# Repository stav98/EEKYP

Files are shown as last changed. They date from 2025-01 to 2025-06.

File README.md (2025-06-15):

# EEKYP
Αποθετήριο με οδηγίες κατασκευής, πηγαίο κώδικα και σχέδια για το έργο <b>"Εξοικονόμηση Ενέργειας και Υδάτινων Πόρων στο δημόσιο σχολείο"</b><br>
**Ομάδα:** Ομάδα ρομποτικής Ε.Κ. Πρέβεζας - 1ου ΕΠΑ.Λ. Πρέβεζας<br/>
**Σχολείο:** Ε.Κ. Πρέβεζας - 1ο ΕΠΑ.Λ. Πρέβεζας (2024-25)<br/>
**Τίτλος έργου:** Εξοικονόμηση Ενέργειας και Υδάτινων Πόρων στο δημόσιο σχολείο<br/> 
<a href="https://openedtech.ellak.gr/robotics2025/exikonomisi-energias-ke-idatinon-poron-sto-dimosio-scholio-e-k-prevezas/">Η παρουσίαση του έργου στο site του ΕΕΛΛΑΚ</a><br>

<b>Τελευταία ενημέρωση 15-6-2025</b>

Περιγραφή έργου
========================
Η ομάδα μας στα πλαίσια του <a href="https://openedtech.ellak.gr/">7ου Πανελλήνιου Διαγωνισμού Ανοιχτών Τεχνολογιών στην Εκπαίδευση</a> ο οποίος διοργανώνεται από τον <a href="https://eellak.ellak.gr/">ΕΕΛΛΑΚ</a> και με θεματική ενότητα <b>"Ανοιχτή Σχεδίαση για έναν Άμεσο Δημόσιο Χώρο"</b> υλοποίησε ένα σύστημα εποπτείας και διαχείρισης ενέργειας και νερού για το σχολείο μας. Το σύστημα τοποθετήθηκε στους χώρους του εργαστηριακού κέντρου (Ε.Κ.) και λειτουργεί δοκιμαστικά. 

Συγκεκριμένα το σύστημα έχει δομηθεί στους τέσσερις ακόλουθους άξονες και στο σχήμα φαίνεται ο τρόπος λειτουργίας και η επικοινωνία των μονάδων:
<ul>
 <li>Α. Εξοικονόμηση νερού</li>
 <li>Β. Εξοικονόμηση ενέργειας</li>
 <li>Γ. Μετεωρολογικός σταθμός</li>
 <li>Δ. Κεντρικό σύστημα διαχείρισης</li>
</ul>

<p align = "center">
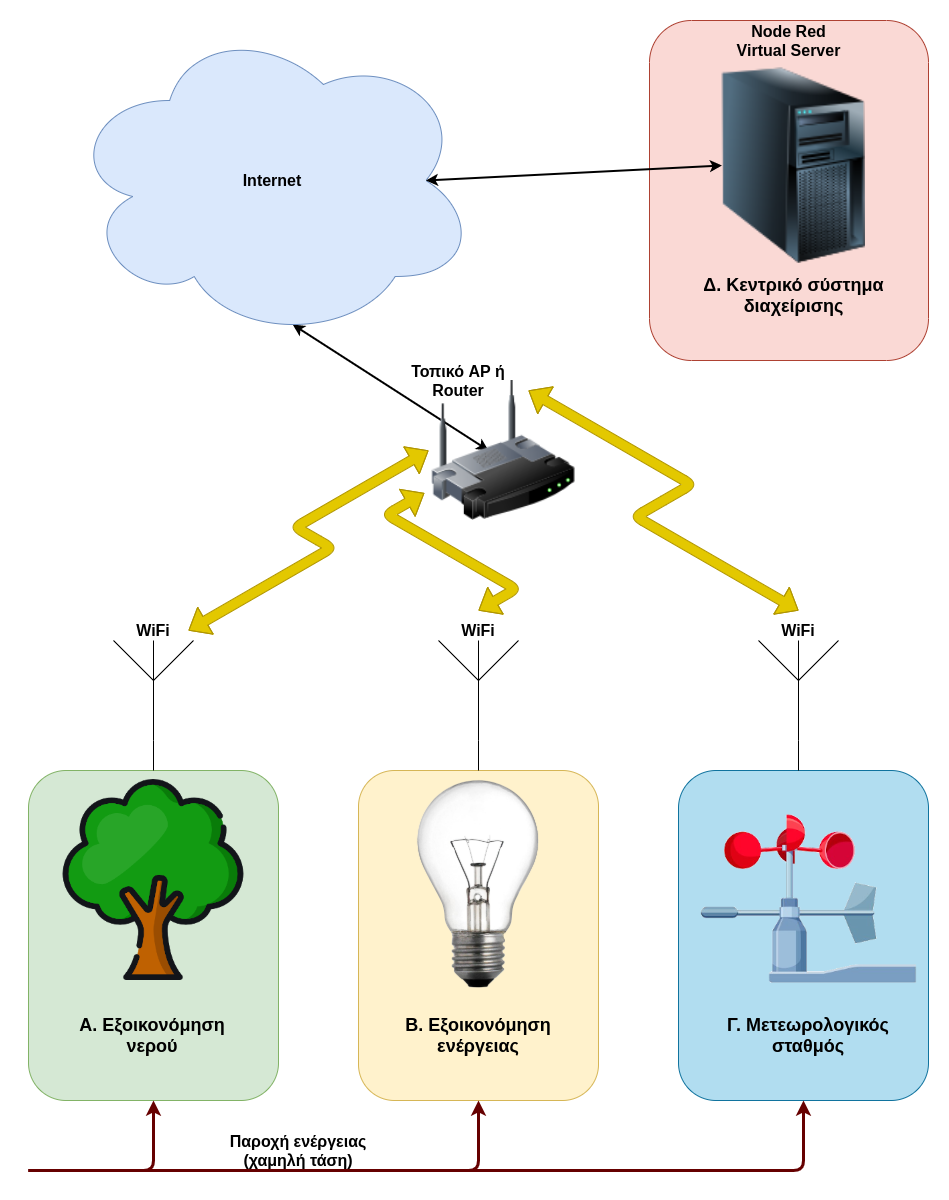
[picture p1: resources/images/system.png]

</p>

Περιεχόμενα
===========

<a href="/documentation/protasi.md">Αρχική πρόταση - Στόχοι - Λίστα υλικών - Προϋπολογισμός</a><br>
<a href="/documentation/eisagogi.md">Γενικές πληροφορίες</a><br>
<a href="Subsystem1_Irrigation/readme.md">Α. Εξοικονόμηση νερού</a><br>
<a href="Subsystem2_PowerSaving/readme.md">Β. Εξοικονόμηση ενέργειας</a><br>
<a href="Subsystem3_WeatherStation/readme.md">Γ. Μετεωρολογικός σταθμός</a><br>
<a href="Subsystem4_NodeRed/readme.md">Δ. Κεντρικό σύστημα διαχείρισης</a><br>

Συμμετέχοντες μαθητές
=====================
Οι μαθητές προέρχονται από το 1ο ΕΠΑ.Λ. Πρέβεζας και από τους τομείς Πληροφορικής - Ηλεκτρολογίας.
<ul>
 <li>Αργυρός Θεμιστοκλής</li>
 <li>Αδάμ Ευάγγελος</li>
 <li>Νάτση Παυλίνα</li>
 <li>Κόκκας Παναγιώτης</li>
</ul>

Υπεύθυνοι καθηγητές: Σταύρος Φώτογλου ΠΕ86 πληροφορικής, Κοτζαμουράτογλου Γιώργος ΠΕ83 ηλεκτρολογίας

Για την υλοποίηση του έργου χρησιμοποιήθηκε ο εξοπλισμός των εργαστηρίων του Εργαστηριακού Κέντρου (Ε.Κ.) Πρέβεζας. Τα υλικά που χρησιμοποιήθηκαν ήταν δωρεά του ΕΕΛΛΑΚ.

Λογισμικό που χρησιμοποιήθηκε
=====================
<p>Χρησιμοποιήθηκε αποκλειστικά λογισμικό ανοιχτού κώδικα.</p>
<ul>
 <li>Λειτουργικό σύστημα Linux. Στους σταθμούς εργασίας στους οποίους έγινε ο σχεδιασμός, ανάπτυξη του έργου υπήρχε εγκατεστημένο Ubuntu 24.04 Mate.</li>
 <li>Draw.io για σχεδιασμό διαγραμμάτων, κυκλωμάτων.</li>
 <li>FreeCad για σχεδιασμό των τρισδιάστατων μοντέλων.</li>
 <li>Gimp για επεξεργασία φωτογραφιών.</li>
 <li>Audacity για επεξεργασία ήχου.</li>
 <li>Simple Screen Recorder για σύλληψη video από την επιφάνεια εργασίας.</li>
 <li>OpenShot για επεξεργασία video.</li>
 <li>LibreOffice για τα κείμενα και εξαγωγή PDF.</li>
 <li>PlatfomIO μαζί με VsCode για την ανάπτυξη του λογισμικού.</li>
 <li>Ubuntu Linux 24.04 server στον εικόνικο διακομιστή με το Mosquitto MQTT brocker και το NodeRed. Επίσης στον φυσικό διακομιστή λειτουργεί Ubuntu 24.04 Server με KVM για εικονικά συστήματα και Docker για τα container.</li> 
</ul>

Βελτιώσεις που πρέπει να γίνουν άμεσα (TODO LIST)
========================================
Επειδή δεν προλάβαμε να ολοκληρώσουμε κατά 100% τον αρχικό σχεδιαμό, αλλά και νέες ιδέες που προέκυψαν κατά την υλοποίηση, την επόμενη σχολική χρονιά θα γίνουν οι ακόλουθες προσθήκες - βελτιώσεις:
<ol>
 <li>Υποσύστημα 1</li>
 <ul>
  <li>Προσθήκη κώδικα στο ESP01 και στο Arduino Nano ώστε να ρυθμίζεται η γωνία ανοίγματος της ηλεκτροβάνας</li>
  <li>Προσθήκη hardware και κώδικα ώστε να εμφανίζει και να στέλνει την τάση λειτουργίας. (Όπως γίνεται στο υποσύστημα 3)</li>
  <li>Υποστήριξη χωρητικών αισθητήρων για την υγρασία εδάφους.</li>
 </ul>
 <li>Υποσύστημα 2</li>
 <ul>
  <li>Προσθήκη hardware (1 σετ με relays) και κώδικα ώστε να συνδέεται με το κουδούνι του σχολείου. Θα προγραμματίζεται με web interface ή από το NodeRed και θα έχει ακρίβεια msec.</li>
  <li>Προσθήκη hardware και κώδικα ώστε να εμφανίζει και να στέλνει την τάση λειτουργίας. (Όπως γίνεται στο υποσύστημα 3)</li>
 </ul>
 <li>Υποσύστημα 3</li>
 <ul>
  <li>Βάψιμο με άσπρο σπρέυ των οργάνων για προστασία από τον ήλιο.</li>
  <li>Υπολογισμός της συσώρευσης βροχής.</li>
  <li>Καλύτερη βαθμονόμηση του ανεμόμετρου.</li>
  <li>Προσθήκη πινάκων διόρθωσης στο web interface του ESP01 ώστε εύκολα ο χρήστης να διορθώνει μη γραμμικές συμπεριφορές του ανεμόμετρου και μετρητή έντασης ηλιακής ακτινοβολίας.</li>
  <li>Προσθήκη hardware για καταμέτρηση των κοντινών κεραυνών (ακτίνα μέχρι 2Km).</li>
 </ul>
 <li>Υποσύστημα 4</li>
 <ul>
  <li>Στο αυτόματο πότισμα διόρθωση του εβδομαδιαίου προγραμματισμού όπως γίνεται για την διαχείρηση ενέργειας.</li>
  <li>Στην διαχείρηση ενέργειας να προστεθεί η γραμμή 2 όπως είναι η γραμμή 1.</li>
  <li>Στον μετεωρολογικό σταθμό να στέλνει δεδομένα κάθε 10 λεπτά στο Weather Cloud.</li>
  <li>Καλύτερη καταγραφή σε αρχεία της κατανάλωσης ρεύματος και νερού.</li>
  <li>Καλύτερη συνεργασία μεταξύ των τριών υποσυστημάτων.</li>
 </ul>
</ol>

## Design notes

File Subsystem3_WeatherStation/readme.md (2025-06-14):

<H3>Γ. Μετεωρολογικός σταθμός</H3>
Σχεδιάσαμε και κατασκευάσαμε έναν μετεωρολογικό σταθμό ο οποίος επικοινωνεί μέσω διαδικτύου με τον κεντρικό σύστημα διαχείρισης ώστε τα δεδομένα να χρησιμοποιούνται από τις προηγούμενες μονάδες. Επίσης στέλνει τα μετεωρολογικά δεδομένα στην ανοιχτή πλατφόρμα WeatherCloud. Τα περισσότερα όργανα του μετεωρολογικού σταθμού τα κατασκευάσαμε στον εκτυπωτή 3D του σχολείου.

Ο μετεωρολογικός σταθμός καταγράφει 8 μετεωρολογικά μεγέθη. Σε σχέση με τον αρχικό σχεδιασμό δεν βάλαμε τον αισθητήρα καταμέτρησης κεραυνών διότι δεν βρήκαμε τον αισθητήρα στην ελληνική αγορά. Ακολουθεί το block διάγραμμα της μονάδας και η τελική υλοποίηση σε λειτουργία:

<table align="center">
 <tr>
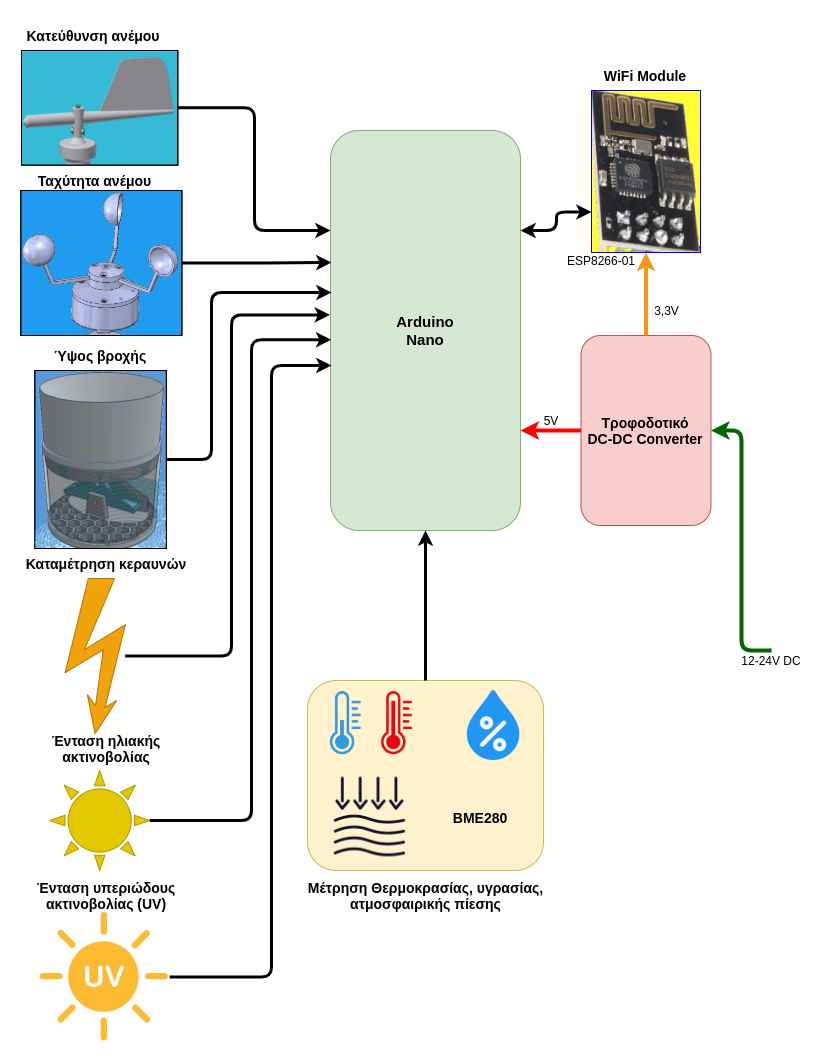
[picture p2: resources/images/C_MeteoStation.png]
  <td></td>
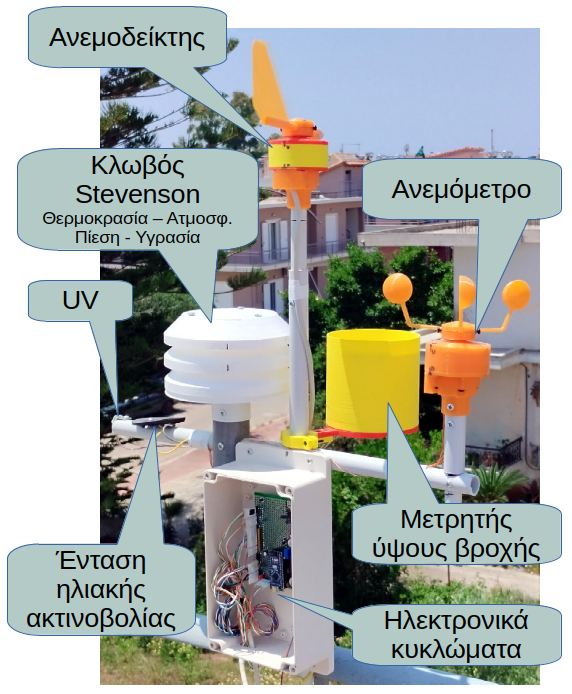
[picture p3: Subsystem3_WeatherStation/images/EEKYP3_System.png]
  <td></td>
  </tr>
</table>

<H3>Κατασκευή ηλεκτρονικού κυκλώματος</H3>
Έγινε κατασκευή του πρωτοτύπου σε διάτρητη πλακέτα perfboard. Πάνω στην πλακέτα τοποθετήθηκαν όλα τα εξαρτήματα και τα αρθρώματα και κολλήθηκαν από την κάτω πλευρά με λεπτά σύρματα. Ακολουθεί το θεωρητικό κύκλωμα της μονάδας.
<p align = "center">
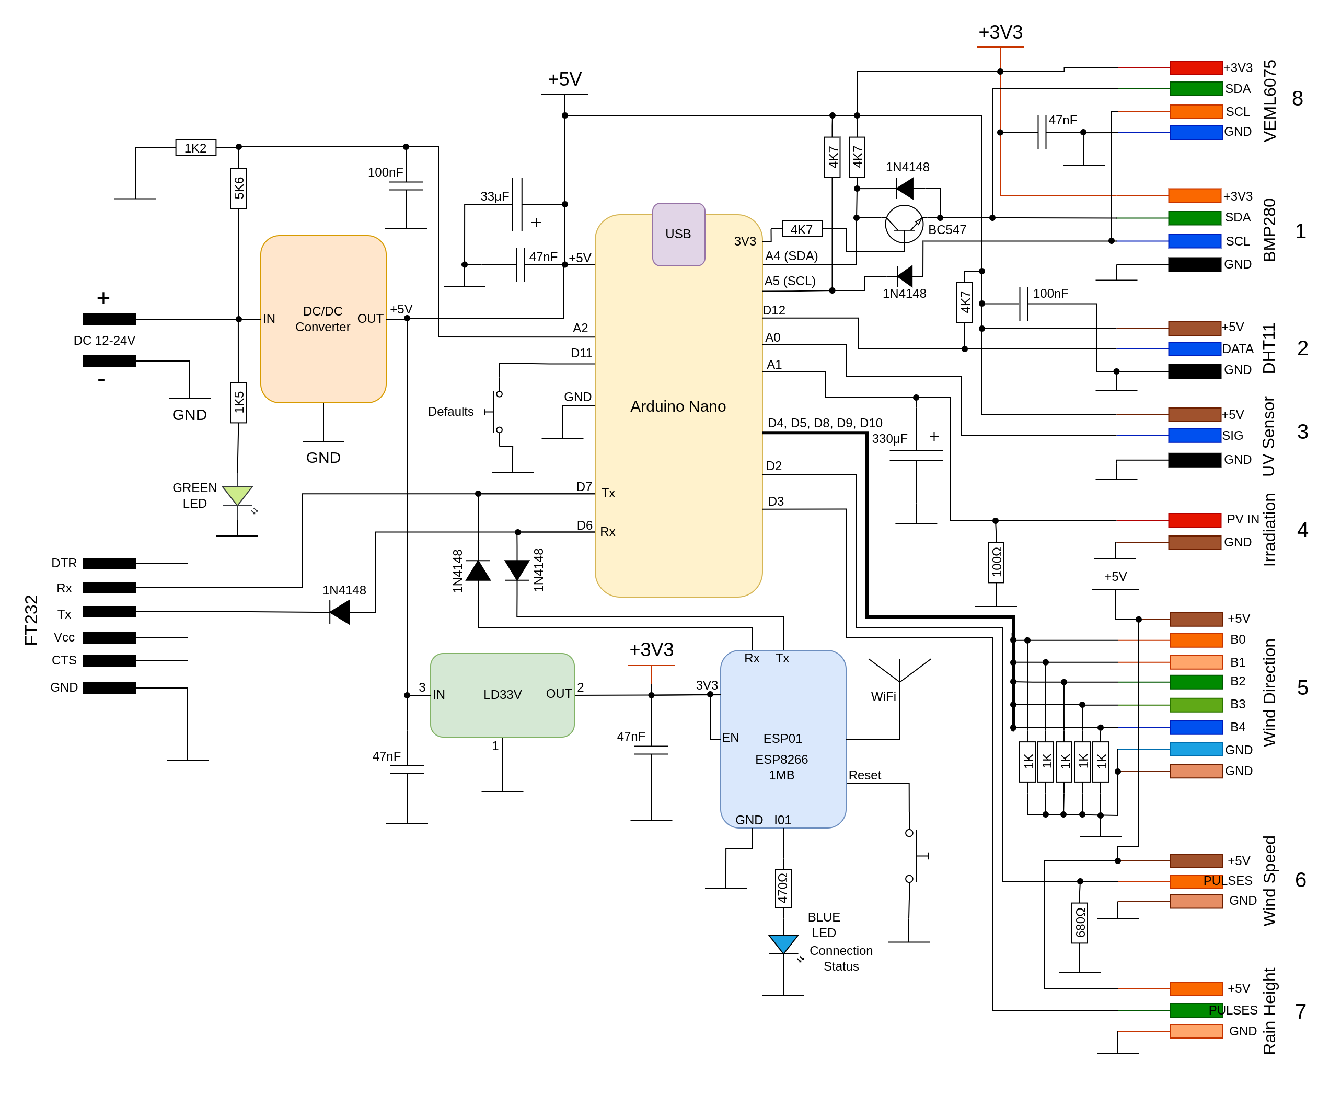
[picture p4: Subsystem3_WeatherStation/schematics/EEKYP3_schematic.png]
  
</p>

<p>
 Στις ακόλουθες εικόνες φαίνεται η κατασκευή του πρωτοτύπου σε πλακέτα perfboard.
</p>
<table align="center">
 <tr>
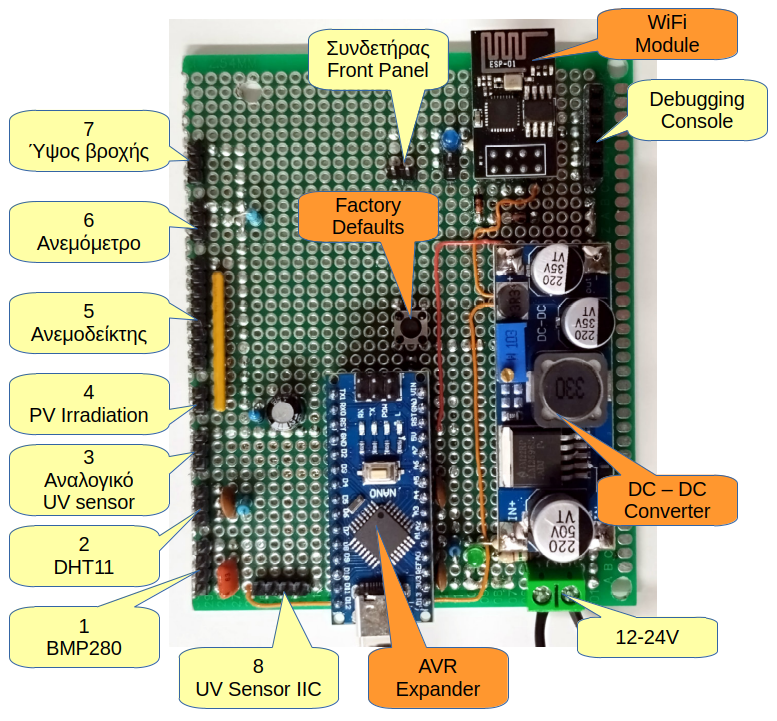
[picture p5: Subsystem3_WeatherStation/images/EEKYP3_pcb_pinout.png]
  <td></td>
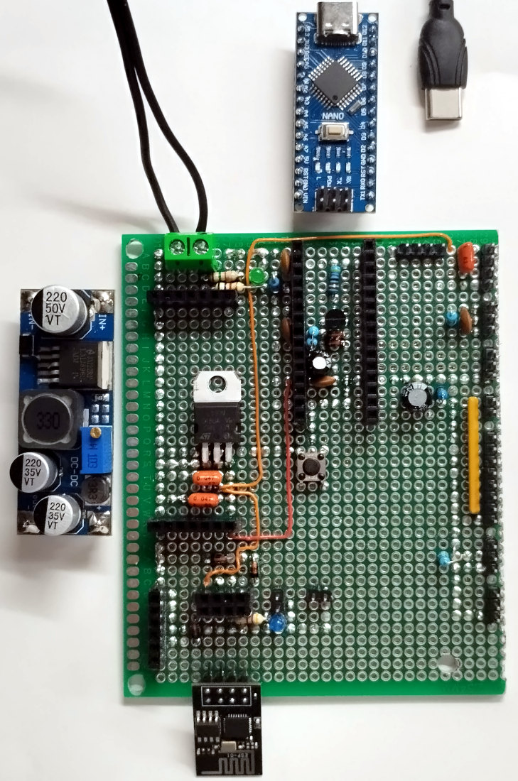
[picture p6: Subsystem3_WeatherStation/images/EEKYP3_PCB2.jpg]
  <td></td>
  </tr>
</table>

Ακολουθεί η περιγραφή όλων των οργανών και παρουσιάζεται ο τρόπος κατασκευής τα σχέδια και ο τρόπος βαθμονόμησης:

## Ανεμόμετρο

Το ανεμόμετρο μετράει την ταχύτητα του ανέμου. Την ιδέα την βρήκαμε στο https://www.yoctopuce.com/EN/article/how-to-measure-wind-part-1 και τα αρχεία για την εκτύπωση 3D υπάρχουν στον κατάλογο 3D.

### Τροποποιήσεις

1. Ρουλεμάν. Τα δύο ρουλεμάν έχουν διαστάσεις 9mm(εξωτερ.), 5mm(εσωτερ.), 3mm(ύψος) και προέρχονται από κεφαλές παλαιών HDD 3,5".
2. Άξονας. Για άξονα χρησιμοποιήσαμε βίδα 5mm(4,9) και την κόψαμε σε μήκος 51mm. Στο κάτω άκρο χαράξαμε εγκοπή ώστε να μπαίνει πλακέ κατσαβίδι.
3. Επειδή υπάρχουν μικρά κενά στην εφαρμογή των ρουλεμάν με την φωλιά, κόβουμε κομμάτι αυτοκόλλητης αλουμινοταινίας 4,5mm x 100mm και τυλίγουμε 2-3 στροφές στην εξωτερική πλευρά των ρουλεμάν.
4. Το ίδιο γίνεται και στον άξονα στα δύο σημεία που εφάπτεται με τα ρουλεμάν. Ταινία αλουμινίου 6,5mm x 56mm και τυλίγουμε 2 στροφές στον άξονα.
5. Μεγαλώνουμε τις οπές στα καπάκια πάνω και κάτω σε διάμετρο 6,6 - 7mm ώστε να περνάει άνετα ο άξονας.
6. Στον εσωτερικό δίσκο με τις 4 σχισμές μεγαλώνουμε την κεντρική οπή σε 4mm και με σπειροτόμο 5mm κάνουμε στροφές. Για σταθεροποίηση, από την πάνω πλευρά βάζουμε ροδέλα στην οποία έχουμε κάνει στροφές και βιδώνει κόντρα.
7. Στον ρότορα με τα κουτάλια μεγαλώνουμε την οπή σε 4mm και κάνουμε στροφές.
8. Ο εσωτερικός δίσκος βιδώνεται στον άξονα. Το ίδιο γίνεται και στον ρότορα κρατώντας με κατσαβίδι πλακέ τον άξονα από κάτω.
9. Για φωτοδίοδο και φωτοτρανζίστορ χρησιμοποιούμε το υπέρυθρο TCRT5000. Βγάζουμε τα δύο στοιχεία από το πλαστικό πλαίσιο και βάζουμε το φωτοτρανζίστορ από την πάνω πλευρά και την φωτοδίοδο από την κάτω.
10. Η φωτοδίοδος συνδέεται στα +5V μέσω αντιστάτη 220Ω και ο συλλέκτης του τρανζίστορ πάει στα +5V. Στην πλακέτα ο εκπομπός γειώνεται μέσω αντιστάτη pulldown 1Κ.

Για την σύνδεση με την πλακέτα θέλουμε 3 καλώδια (5V, GND και τα δεδομένα από τον εκπομπό του φωτοτρανζίστορ που είναι παλμοί μεταβλητής συχνότητας ανάλογα με την ταχύτητα περιστροφής του ρότορα.)

<table align="center">
 <tr>
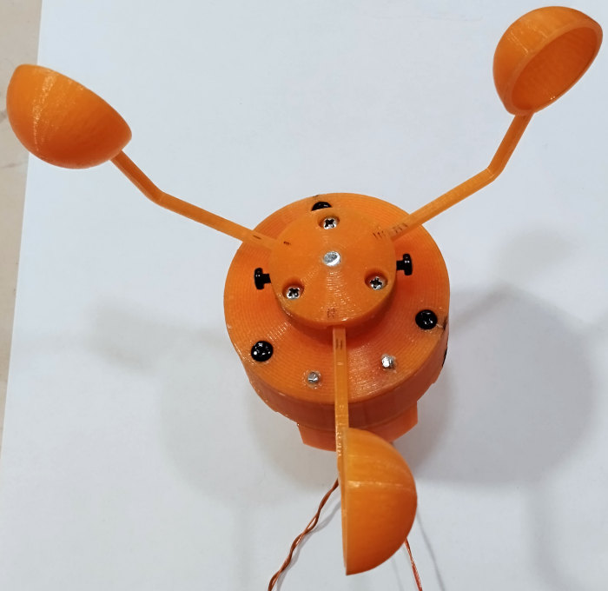
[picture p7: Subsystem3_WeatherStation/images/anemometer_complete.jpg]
  <td></td>
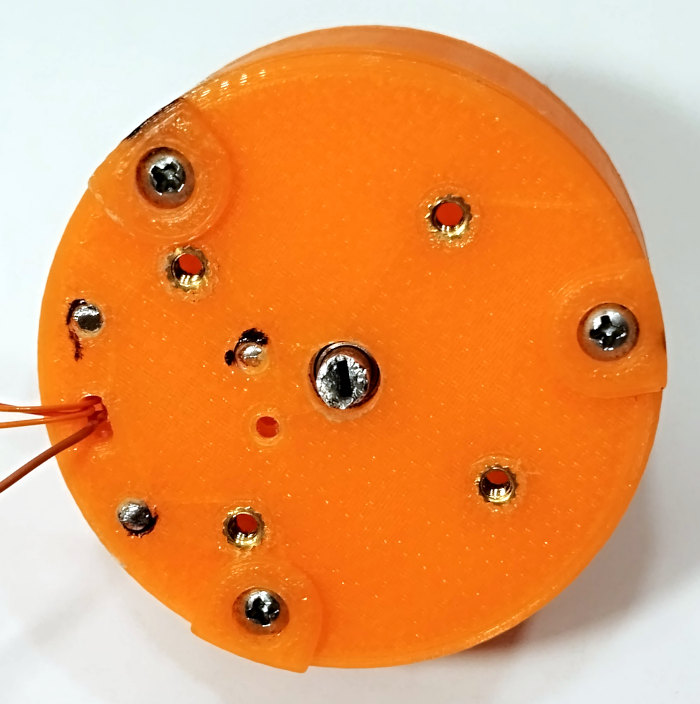
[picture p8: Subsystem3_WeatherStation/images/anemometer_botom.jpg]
  <td></td>
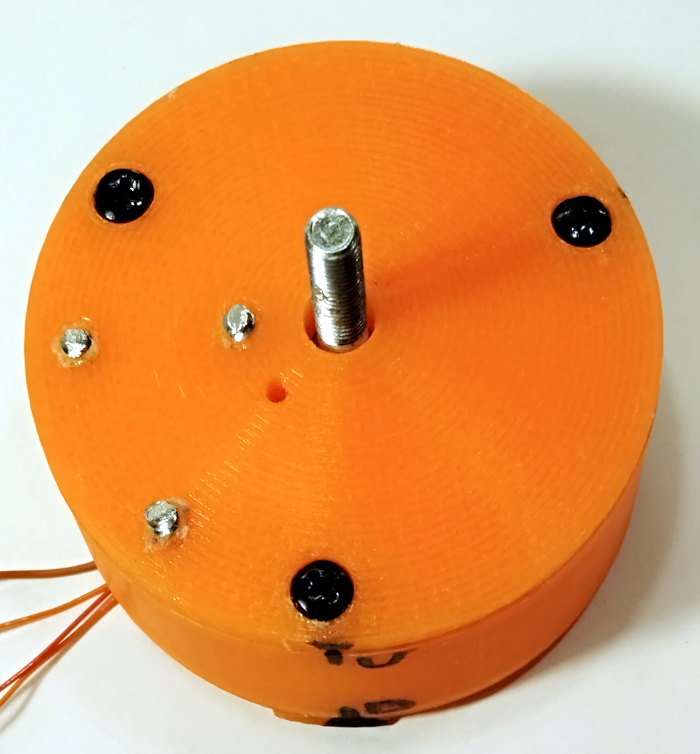
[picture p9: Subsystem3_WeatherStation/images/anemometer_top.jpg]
   <td></td>
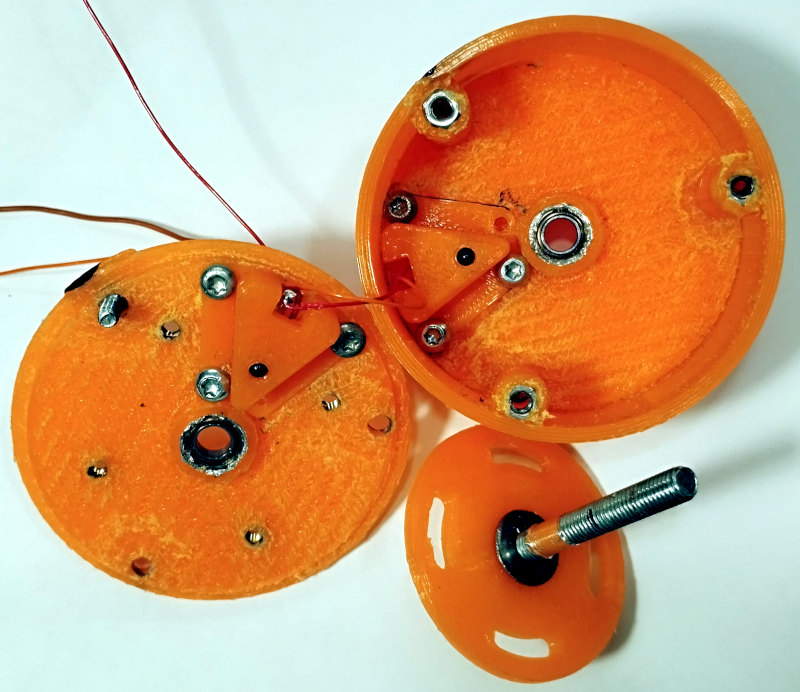
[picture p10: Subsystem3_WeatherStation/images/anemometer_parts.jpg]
   <td></td>
  </tr>
</table>

<p align = "center">
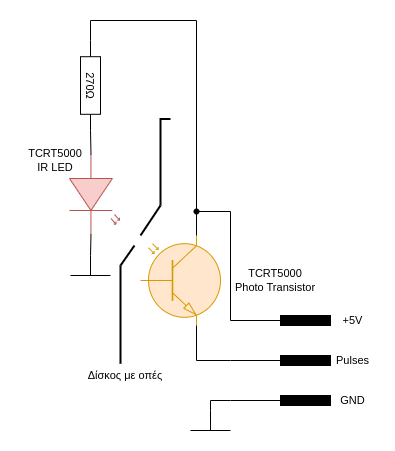
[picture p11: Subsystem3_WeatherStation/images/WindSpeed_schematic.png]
  
</p>

### Βαθμονόμηση

Μια μέρα με άπνοια τοποθετούμε το ανεμόμετρο σταθερά σε ένα αυτοκίνητο. Προσοχή !!! πρέπει να δεθεί πολύ σταθερά ώστε να αποφύγουμε ατυχήματα. Επίσης πρέπει να είναι αρκετά πάνω από την οροφή. Με ένα φορητό υπολογιστή συνδεδεμένο στο Arduino nano και παρουσιάζοντας τις μετρήσεις στο πρόγραμμα τερματικού PUTTY μετράμε τις στροφές / λεπτό της περιστροφής του ρότορα. (Για μια στροφή έχουμε 4 διακοπές). Καταγράφουμε τα rpm για ταχύτητες από 10 - 80Km/h με βήμα ανά 10Km/h. Αν υπάρχει μη γραμμική σχέση βάζουμε αυτές τις τιμές σε πίνακα και υπολογίζουμε τις ενδιάμεσες τιμές.  

## Ανεμοδείκτης

Ο ανεμοδείκτης δείχνει την κατεύθυνση του ανέμου. Την ιδέα την βρήκαμε στο https://www.yoctopuce.com/EN/article/how-to-measure-wind-part-2 και τα αρχεία για την εκτύπωση 3D υπάρχουν στον κατάλογο 3D. Ο ανεμοδείκτης μας χρησιμοποιεί την τεχνική του κώδικα Gray και συγκεκριμένα το Single Track Gray Code (STGC). Εδώ έχουμε 5 υπέρυθρα Led στο κάτω μέρος του οργάνου τα οποίο επισκιάζονται ή όχι ανάλογα με την θέση του δίσκου. Οι τρεις οπές του δίσκου έχουν μήκη σύμφωνα με τον κώδικα Gray 5 bit. Από την πάνω πλευρά υπάρχουν 5 υπέρυθρα φωτοτρανζίστορ ακριβώς απέναντι από καθένα Led. Οι δυνατοί συνδιασμοί που παράγονται με 5 bits είναι 32, αλλά σύμφωνα με τον τροποποιημένο κώδικα μπορούμε να έχουμε 30 συνδιασμούς. Δηλαδή 360 μοίρες / 30 = 12 μοίρες. Επομένως μπορούμε να ανιχνεύσουμε 30 διαφορετικές διευθύνσεις του ανέμου το οποίο είναι υπέρ αρκετό. Για τα υπέρυθρα Led και φωτοτρανζίστορ χρησιμοποιήθηκαν 5 TCRT5000. <a href="docs/Gray_code.pdf" title="Παρουσίαση κώδικα">Εδώ στο αρχείο</a> υπάρχουν οι συνδιασμοί του τροποποιημένου κώδικα που χρησιμοποιήσαμε.

<p align = "center">
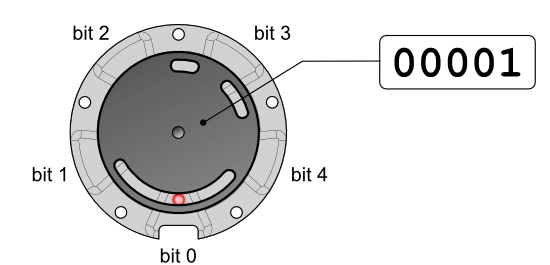
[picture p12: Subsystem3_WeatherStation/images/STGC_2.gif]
  
</p>

### Τροποποιήσεις

Οι τροποποιήσεις είναι ίδιες με αυτές του ανεμόμετρου.

Για την σύνδεση με την πλακέτα θέλουμε 7 καλώδια (5V, GND και τα δεδομένα των 5 bits του κώδικα Gray.)

<table align="center">
 <tr>
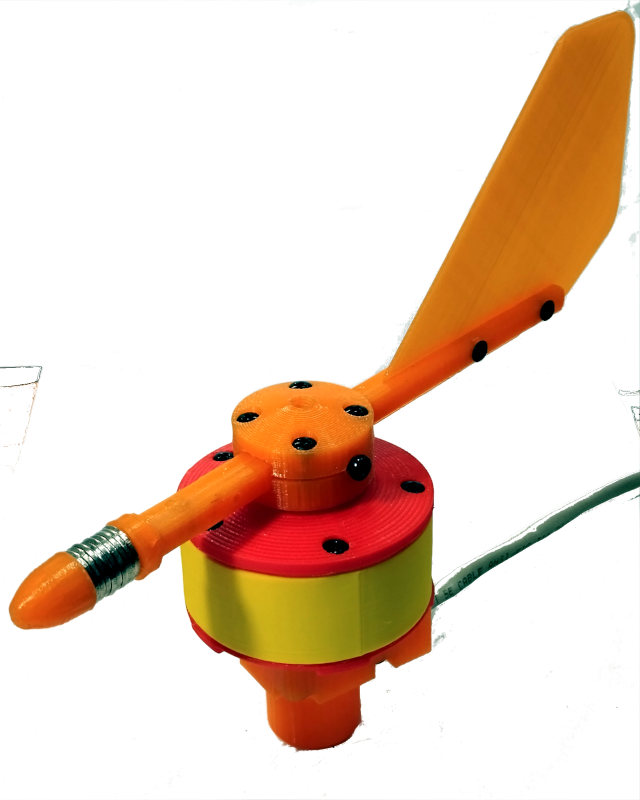
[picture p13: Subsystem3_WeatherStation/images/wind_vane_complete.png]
  <td></td>
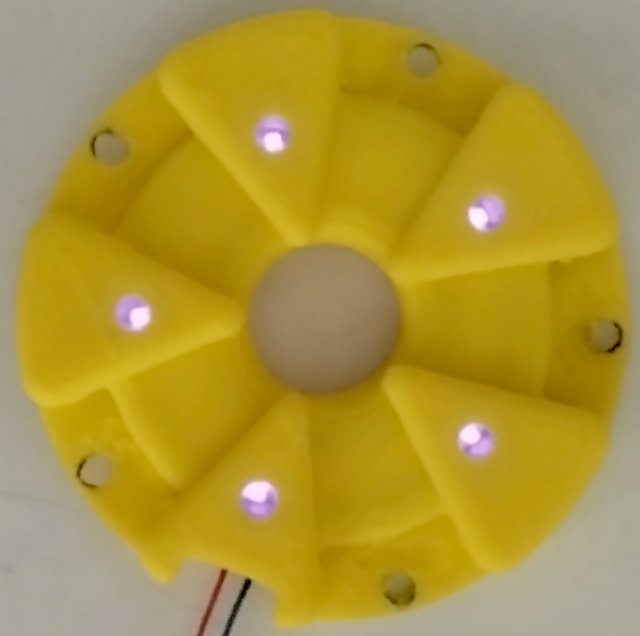
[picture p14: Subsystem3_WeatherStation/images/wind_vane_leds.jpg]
  <td></td>
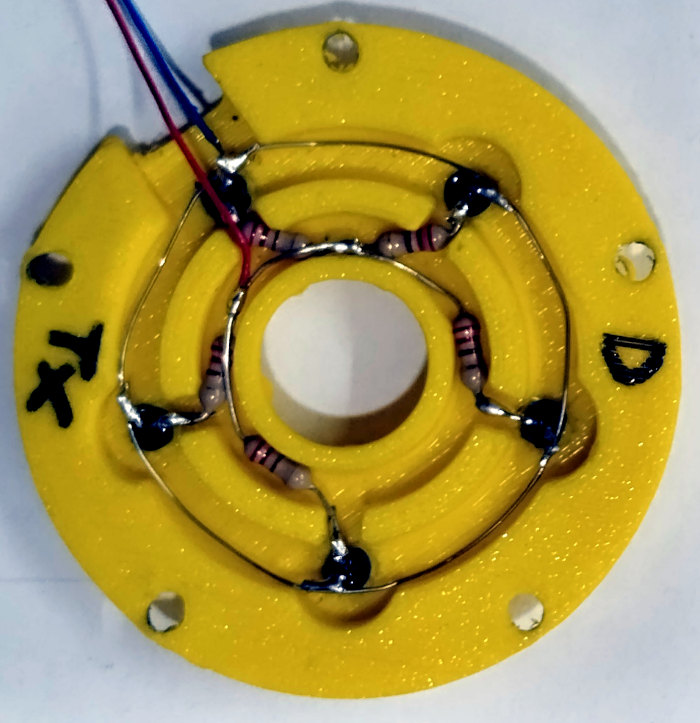
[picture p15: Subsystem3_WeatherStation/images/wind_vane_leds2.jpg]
   <td></td>
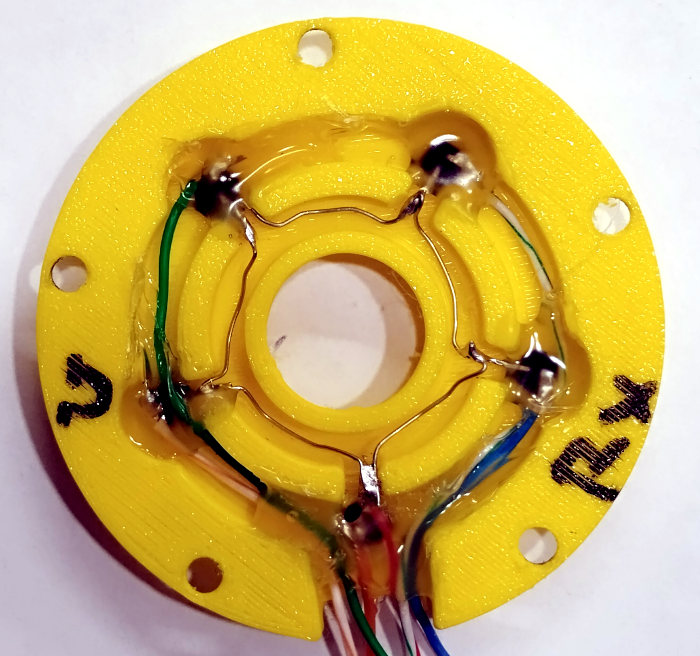
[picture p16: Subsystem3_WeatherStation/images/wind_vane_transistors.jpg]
   <td></td>
  </tr>
</table>

<table align="center">
 <tr>
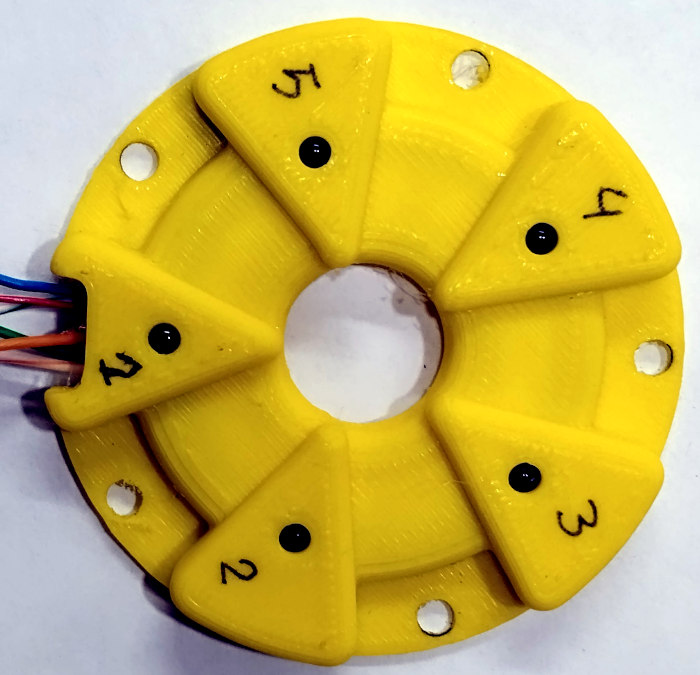
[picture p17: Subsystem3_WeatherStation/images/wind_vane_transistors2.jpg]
  <td></td>
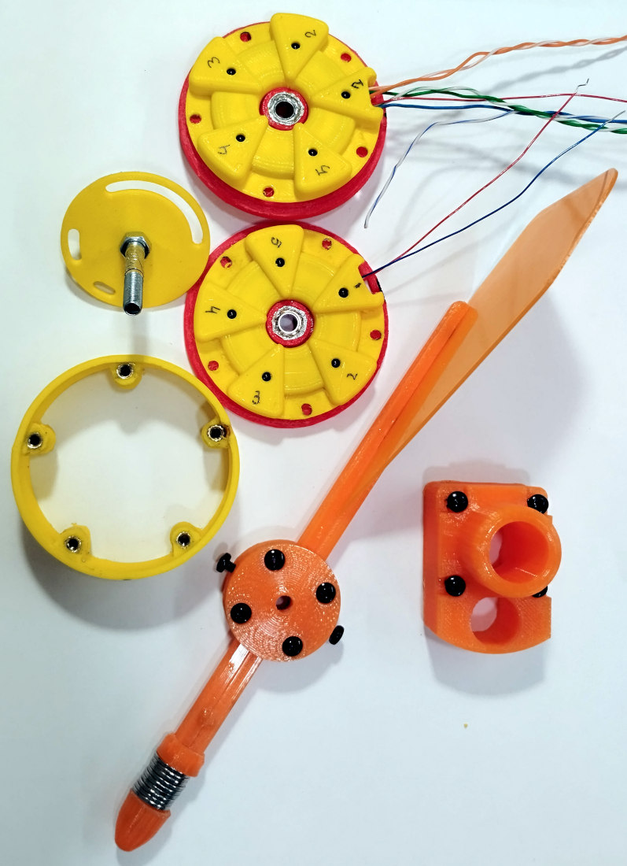
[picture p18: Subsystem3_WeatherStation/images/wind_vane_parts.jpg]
  <td></td>
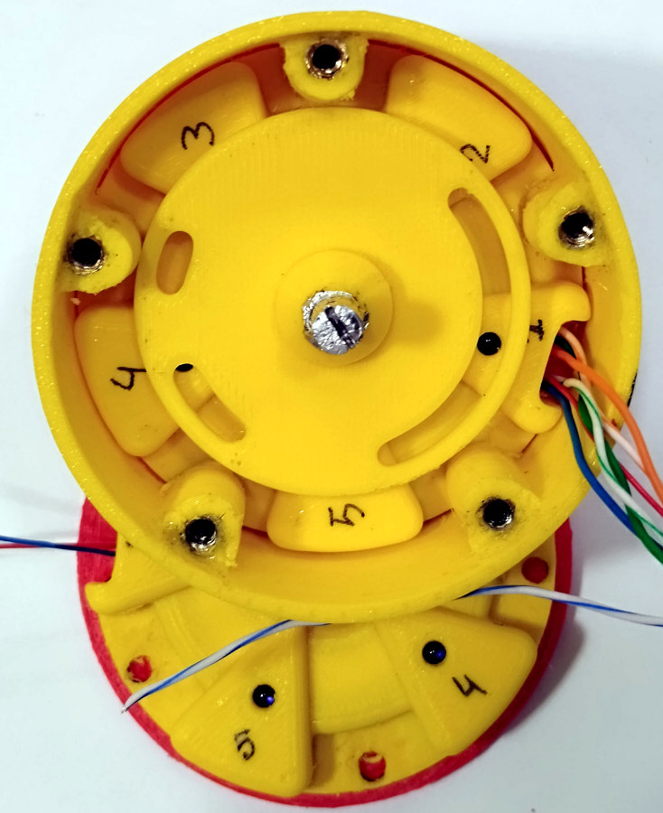
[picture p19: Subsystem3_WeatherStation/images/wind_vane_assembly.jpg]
   <td></td>
  </tr>
</table>

<p align = "center">
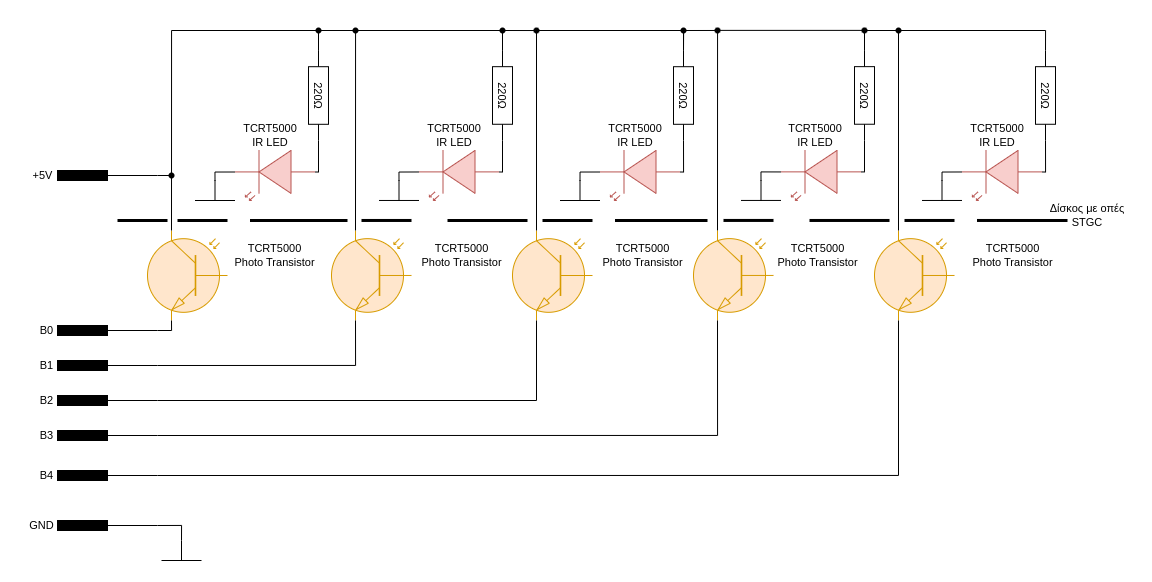
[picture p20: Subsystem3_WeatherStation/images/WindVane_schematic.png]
  
</p>

### Βαθμονόμηση
Η βαθμονόμηση του ανεμοδείκτη είναι εύκολη. Φροντίζουμε να περιστρέψουμε όλο το σώμα του ανεμοδείκτη έτσι ώστε όταν ο ανεμοδείκτης είναι στραμμένος στις 0 μοίρες να δείχνει στον βορά.

## Μετρητής ύψους βροχής

Ο μετρητής ύψους βροχής μετράει την βροχόπτωση σε χιλιοστά. Τα αρχεία για την εκτύπωση 3D υπάρχουν στον κατάλογο 3D. Το νερό συλλέγεται από ένα χωνί διαμέτρου 9,6cm και οδηγείται σε ένα μηχανισμό τραμπάλας με δύο μικρά δοχεία στα άκρα. Όταν το δοχείο γεμίσει, η τραμπάλα γυρίζει λόγω της βαρύτητας και αδειάζει το νερό, ενώ το άλλο άκρο έχει ανέβει και γεμίζει από το χωνί. Όσο πιο πολύ είναι το νερό τόσο γρηγορότερα πάλλεται η τραμπάλα. Στα δύο άκρα έχουν τοποθετηθεί δύο μικροί μαγνήτες ίδιου βάρους. Εμείς ανιχνεύουμε τις ταλαντώσεις του ενός άκρου με έναν αισθητήρα hall. Το παλμικό σήμα οδηγείται σε ένα pin του arduino με δυνατότητα διακοπής. (External interrupt)  

<p align = "center">
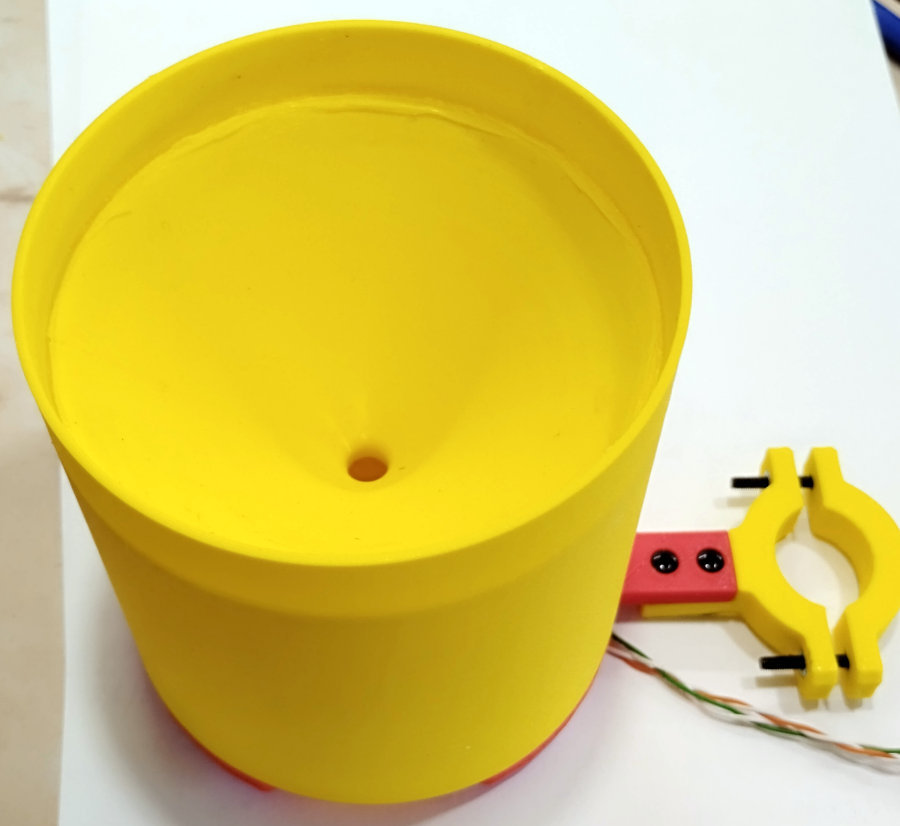
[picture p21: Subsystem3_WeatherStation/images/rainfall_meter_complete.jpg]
  
</p>

### Τροποποιήσεις

Για άξονα χρησιμοποιήσαμε μια βίδα διαμέτρου 3mm και για μαγνήτες βάλαμε μικρά κομματάκια από μαγνήτη κίνησης της κεφαλής ενός σκληρού δίσκου. Σπάμε τον μαγνήτη σε μικρά κομμάτια ίδιου μεγέθους. Από τους δύο μαγνήτες μόνο ο ένας χρησιμοποιείται ενώ ο άλλος λειτουργεί ως αντίβαρο. Επίσης πρέπει να προσέξουμε στην τοποθέτηση των πόλων του ενεργού μαγνήτη ώστε το μαγνητικό πεδίο να επιδρά στον αισθητήρα hall. 

Για την σύνδεση με την πλακέτα θέλουμε 3 καλώδια (5V, GND και το παλμικό σήμα)

<table align="center">
 <tr>
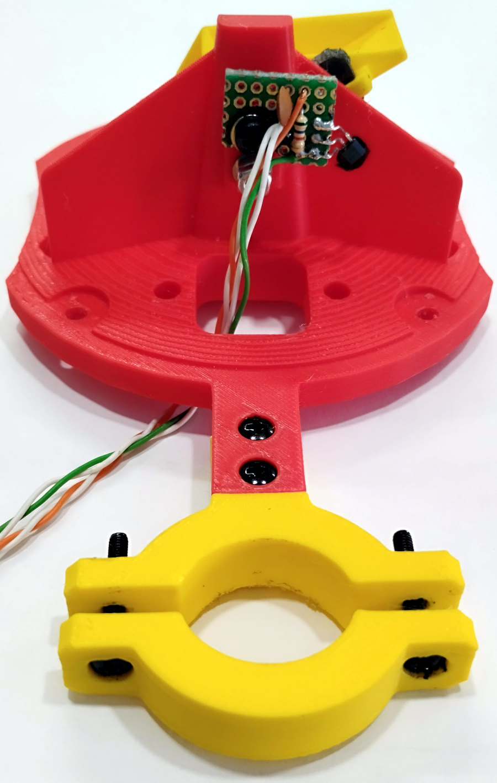
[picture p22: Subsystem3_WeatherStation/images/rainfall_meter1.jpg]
  <td></td>
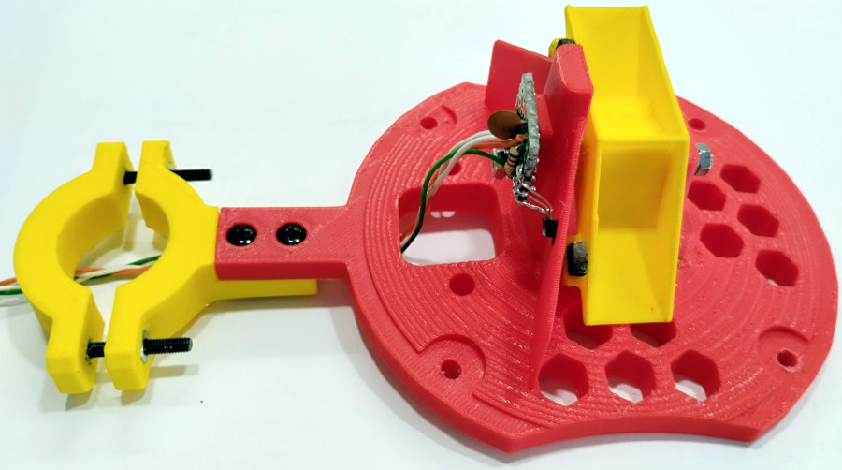
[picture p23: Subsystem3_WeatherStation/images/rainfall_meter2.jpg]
  <td></td>
  </tr>
</table>

<p align = "center">
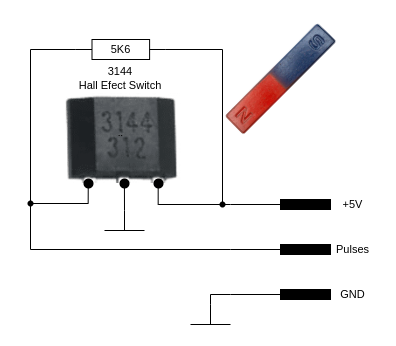
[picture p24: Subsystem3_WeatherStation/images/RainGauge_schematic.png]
  
</p>

### Βαθμονόμηση

Με μια σύριγγα στάζουμε νερό στην τραμπάλα και βρίσκουμε τα ml που χρειάζονται για να αλλάξει η κατάσταση. Είδαμε ότι με 3 ml αλλάζει η ισορροπία της τραμπάλας. Για μεγαλύτερη ακρίβεια χρησιμοποιούμε μια σύριγγα 20ml και στάζουμε αργά νερό στο χωνί και μετράμε παλμούς. Έτσι μετρήσαμε ότι για 20ml κάνει 7 παλμούς και για 40ml κάνει 14 παλμούς. Δηλαδή 20 / 7 = 2,9ml ανά παλμό. Επειδή κάνουμε διακοπή στον microcontroller με κάθοδο παλμού τότε για 3ml θα μετρήσει ένα παλμό. Και τώρα λίγοι υπολογισμοί:

Διάμετρος χωνιού 9,6cm δηλαδή ακτίνα 4,8cm δηλαδή εμβαδόν = π*r<sup>2</sup> = 3.14 * 4,8<sup>2</sup> = 72,4cm<sup>2</sup>.
Επομένως αν το ύψος νερού είναι 10mm = 1cm τότε ο όγκος θα είναι 72,4cm<sup>2</sup> * 1cm = 72,4cm<sup>3</sup> ή 72,4ml.
72,4ml / 3ml = 24 παλμοί. Και σύμφωνα με τα παραπάνω δημιουργείται ο ακόλουθος πίνακας.

<table align="center">
 <tr>
  <td><strong>Ύψος</strong></td><td><strong>Όγκος</strong></td><td><strng>Παλμοί</strng></td>
 </tr>
 <tr>
  <td>10mm</td><td>72,4ml</td><td>24</td>
 </tr>
 <tr>
  <td>20mm</td><td>144,8ml</td><td>46</td>
 </tr>
 <tr>
  <td>30mm</td><td>217,2ml</td><td>72</td>
 </tr>
 <tr>
  <td>40mm</td><td>290ml</td><td>96</td>
 </tr> 
 <tr>
  <td>50mm</td><td>362,4ml</td><td>120</td>
 </tr>
</table>

Αν σε μια ώρα μετρήσουμε π.χ. 10 παλμούς τότε έχουμε 10 * 3 = 30ml / 7,24 = 4,1mm ύψος βροχής. Για κάθε 1mm ύψος βροχής ο μικροελεγκτής δέχεται 2,5 παλμούς. 
Ή για κάθε 1mm βροχής έχουμε όγκο 7,24ml => 7,24 / 2,9 = 2,5 παλμοί.

## Αισθητήρες ατμοσφαιρικής πίεσης, θερμοκρασίας και υγρασίας
Οι αισθητήρες αυτοί τοποθετούνται σε μια μικρή πλακέτα η οποία με την σειρά της τοποθετείται μέσα στον μετεωρολογικό κλωβό τύπου Stevenson που εκτυπώσαμε στον εκτυπωτή 3D. Για την θερμοκρασία και την ατμοσφαιρική πίεση χρησιμοποιήσαμε τον αισθητήρα BMP280 ο οποίος συνδέεται με το Arduino nano με διασύνδεση IIC. Για μέτρηση της σχετικής υγρασίας χρησιμοποιήσαμε τον αισθητήρα DHT11 ο οποίος παρέχει επιπλέον και μέτρηση θερμοκρασίας. Ο DHT11 συνδέεται με ένα ξεχωριστό σειριακό δίαυλο.

<table align="center">
 <tr>
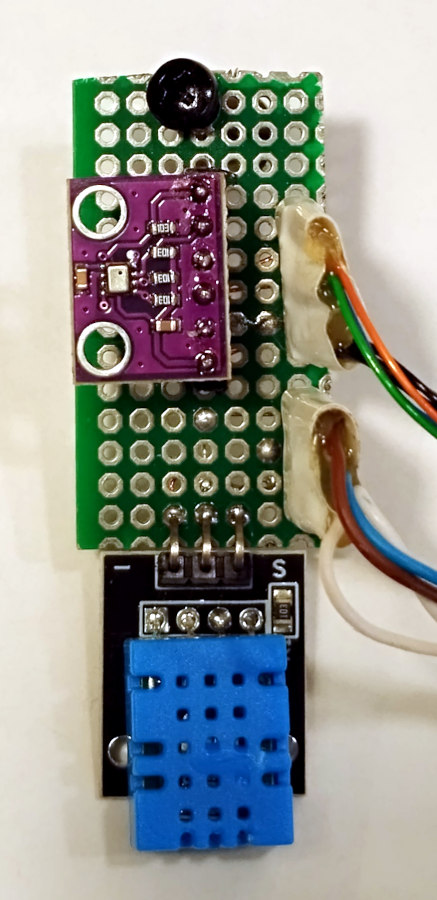
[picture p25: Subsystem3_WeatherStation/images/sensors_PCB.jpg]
  <td></td>
  <td></td>
  </tr>
</table>

## Αισθητήρες ακτινοβολίας UV και έντασης ηλιακής ακτινοβολίας
<p>Για την μέτρηση του δείκτη υπέρυθρης ακτινοβολίας UV έχουμε την δυνατότητα να χρησιμοποιήσουμε δύο αισθητήρες. Τον αναλογικό SEN0162 ο οποίος συνδέεται σε μια αναλογική είσοδο του arduino nano ή τον ψηφιακό VEML6075 ο οποίος συνδέεται με δίαυλο IIC και είναι πολύ πιο ακριβής και ευαίσθητος από τον πρώτο. Εμείς στην τελική φάση προτιμήσαμε τον ψηφιακό.</p>

<p>Για την μέτρηση της έντασης ηλιακής ακτινοβολίας πρέπει να χρησιμοποιηθεί ένα ειδικό όργανο που ονομάζεται πυρανόμετρο. Επειδή έχει υψηλό κόστος προτιμήσαμε να βάλουμε ένα μικρό φωτοβολταϊκό 3x3cm το οποίο συνδέεται σε μια αναλογική είσοδο. Με την μέθοδο αυτή δεν έχουμε καλή ακρίβεια αλλά αρκετή για ένα μαθητικό έργο. Και τα δύο όργανα και ειδικά ο μετρητής ακτινοβολίας UV πρέπει να τοποθετηθούν έξω από κάθε κουτί ή τζάμι γιατί έχουμε μεγάλη απόσβεση της ακτινοβολίας UV. Για να προστατέψουμε τον αισθητήρα από την υγρασία τον περνάμε πολλές στρώσεις διάφανο πλαστικοποιητικό σπρέυ εκτός από το παραθυράκι για την είσοδο του φωτός.</p>

<table align="center">
 <tr>
  <td></td>
  <td></td>
  </tr>
</table>

## Λογισμικό
<p>Το λογισμικό όπως και στα άλλα υποσυστήματα είναι γραμμένο σε γλώσσα wiring (c - c++) και για τους δύο microcontrollers. Επιπλέον υπάρχει και αρκετή HTML, CSS και JavaScript (JQuery) για την υλοποίηση του web interface.</p>

<table align="center">
 <tr>
  <td></td>
  <td></td>
  </tr>
</table>

Βίντεο δοκιμών του μετεωρολογικού σταθμού
<p align = "center"></p>

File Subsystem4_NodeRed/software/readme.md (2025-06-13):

Εδώ βρίσκονται τα flows για το Node Red.

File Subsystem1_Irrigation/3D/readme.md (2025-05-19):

Αρχεία για εκτύπωση στον εκτυπωτή 3D των βάσεων στήρηξης των βανών και των servomotors.

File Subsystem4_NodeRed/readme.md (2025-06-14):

<H3>Δ. Κεντρικό σύστημα διαχείρισης</H3>
Αυτό είναι το σύστημα συλλογής και καταγραφής δεδομένων από τις προηγούμενες μονάδες. Έχει υλοποιηθεί με το λογισμικό ανοιχτού κώδικα Node RED το οποίο λειτουργεί σε έναν εικονικό διακομιστή (KVM) του Ε.Κ Πρέβεζας. Εδώ υπάρχουν τρεις καρτέλες (tabs) μία για κάθε υποσύστημα. Σε αυτό το υποσύστημα γίνεται η επεξεργασία των ακατέργαστων δεδομένων από τα τρία προηγούμενα. Έτσι μπορούν να ληφθούν αποφάσεις π.χ. πότε πρέπει να ξεκινήσει το πότισμα, πόσο νερό καταναλώθηκε τον προηγούμενο μήνα ή πότε πρέπει να ανάψουν τα φώτα κλπ. Επίσης τα δεδομένα καταγράφονται και παρουσιάζονται με γραφήματα. Τέλος υπάρχει η δυνατότητα αποστολής μηνυμάτων μέσω Viber ή Telegram ακόμη και ο χειρισμός των δύο πρώτων υποσυστημάτων.</p>

Στην εικόνα φαίνεται η διεπαφή χρήστη του Node Red 
<p align = "center">
  
</p>

Και ο τρόπος προγραμματισμού με blocks και NodeJS (Java Script)
<p align = "center">
  
</p>

Βίντεο παρουσίασης των λειτουργιών του υποσυστήματος 3
<p align = "center"></p>

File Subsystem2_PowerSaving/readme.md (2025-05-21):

<H3>Β. Εξοικονόμηση ενέργειας</H3>
Κατασκευάσαμε μονάδα εποπτείας και ελέγχου σε δύο γραμμές φωτισμού για τον διάδρομο του Ε.Κ. Η μονάδα μετράει συνεχώς την κατανάλωση ενέργειας της παροχής και ανάβει μόνο τα απαραίτητα φώτα ανάλογα με το φως ημέρας. Η μονάδα επικοινωνεί μέσω διαδικτύου με το κεντρικό σύστημα διαχείρισης.
<p align = "center">
  
</p>
<H3>Κατασκευή ηλεκτρονικού κυκλώματος</H3>
Έγινε κατασκευή του πρωτοτύπου σε διάτρητη πλακέτα perfboard. Πάνω στην πλακέτα τοποθετήθηκαν όλα τα εξαρτήματα και τα αρθρώματα και κολλήθηκαν από την κάτω πλευρά με λεπτά σύρματα. Ακολουθεί το θεωρητικό κύκλωμα της μονάδας.
<p align = "center">
  
</p>
Η τελική μορφή του πρωτοτύπου και η τοποθέτηση του στο αδιάβροχο ηλεκτρολογικό κουτί.
<table align="center">
 <tr>
  <td></td>
  <td></td>
   <td></td>
  </tr>
</table>
Στην ακόλουθη εικόνα φαίνεται η περιγραφή των αρθρωμάτων και των συνδέσεων.
<p align = "center">
  
</p>

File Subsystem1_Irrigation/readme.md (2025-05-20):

<H2>Α. Εξοικονόμηση νερού</H2>
Σχεδιάσαμε και κατασκευάσαμε μονάδα αυτόματου ποτίσματος με αισθητήρες υγρασίας και θερμοκρασίας στην ρίζα των φυτών ώστε να ποτίζονται αυτόματα μόνο όταν είναι απαραίτητο. Αν και στον αρχικό σχεδιασμό σκοπευαμε να κατασκευάσουμε τουλάχιστον δύο μονάδες, τελικά κατασκευάσαμε μία διπλή. Η μονάδα υποστηρίζει δύο ανεξάρτητες γραμμές ποτίσματος με ανεξάρτητους αισθητήρες και τοποθετήθηκε στον κήπο του Ε.Κ. Οι μονάδες αυτές επικοινωνούν μέσω διαδικτύου με το κεντρικό σύστημα διαχείρησης. 
Ακολουθεί το block διάγραμμα της μονάδας
<p align = "center">
  
</p>
<H3>Κατασκευή ηλεκτρονικού κυκλώματος</H3>
Έγινε κατασκευή του πρωτοτύπου σε διάτρητη πλακέτα perfboard. Πάνω στην πλακέτα τοποθετήθηκαν όλα τα εξαρτήματα και τα αρθρώματα και κολλήθηκαν από την κάτω πλευρά με λεπτά σύρματα. Ακολουθεί το θεωρητικό κύκλωμα της μονάδας.
<p align = "center">
  
</p>
Κόλληση των εξαρτημάτων και αρθρωμάτων σύμφωνα με το προηγούμενο σχέδιο
<table align="center">
 <tr>
  <td></td>
  <td></td>
  </tr>
</table>
Το τελικό αποτέλεσμα και οι ηλεκτρολογικές συνδέσεις των αισθητήρων - ενεργοποιητών
<table align="center">
 <tr>
  <td></td>
  <td></td>
  </tr>
</table>
<H3>Σχεδιασμός και εκτύπωση συστήματος ηλεκτροβάνας</H3>
Επειδή οι ηλεκτροβάνες άρδευσης είναι ακριβές και οι φθηνότερες βαλβίδες λειτουργούν μόνο σε δύο καταστάσεις (ανοιχτό/κλειστό) αποφασίσαμε να χρησιμοποιήσουμε απλές βάνες (κόστος περίπου 1€) και να τις περιστρέφουμε με servo κινητήρα. Για τον λόγο αυτό σχεδιάσαμε στο Freecad μια απλή βάση στήριξης της βάνας και του servo motor. Τα αρχεία σε μορφή stl <a href="3D">βρίσκονται εδώ</a>.
<table align="center">
 <tr>
  <td></td>
  <td>
  </td>
  </tr>
</table>
<H3>Προγραμματισμός</H3>
Η μονάδα έχει δύο modules με microcontrollers. Το Arduino Nano και το ESP01. Το πρώτο δέχεται τα σήματα των αισθητήρων και ελέγχει τους ενεργοποιητές, ενώ το δεύτερο είναι υπεύθυνο για την σύνδεση στο διαδίκτυο μέσω WiFi και γενικά κάνει την περισσότερη δουλειά. Τα δύο modules επικοινωνούν μέσω σειριακής θύρας σε ρυθμό 9600bps. Ο κώδικας είναι γραμμένος σε C++ (Arduino wiring) και χρησιμοποιήσαμε το IDE vscode με την επέκταση του PlatformIO. Επίσης στο ESP01 λειτουργεί και ένας mini Web Server γι' αυτό έχουμε και λίγο κώδικα σε HTML καθώς και JQuery - JavaScript.
<H3>Δοκιμές</H3>
Έγιναν πολλές δοκιμές και πολλές διορθώσεις μέχρι να πετύχουμε ικανοποιητικά αποτελέσματα. Αρχικά δοκιμάσαμε μέσα στο εργαστήριο την επικοινωνία με το διαδίκτυο, τους αισθητήρες, την κίνηση των ηλεκτροβανών και μετά έγιναν οι δοκιμές σε εξωτερικό περιβάλλον.
<table align="center">
 <tr>
  <td></td>
  <td></td>
  <td>
  </td> 
  </tr>
</table>
<H3>Μηχανολογική κατασκευή - Τοποθέτηση σε αδιάβροχο ηλεκτρολογικό κουτί</H3>
Με την βοήθεια του μαθητή από τον ηλεκτρολογικό τομέα έγινε η κατασκευή του κουτιού. Επειδή η μονάδα λειτουργεί σε εξωτερικό χώρο πρέπει να είναι προστατευμένη από υγρασία. Να επισημάνουμε ότι η μονάδα λειτουργεί με μέγιστη τάση έως 24V επομένως δεν υπάρχει απολύτως κανένας κίνδυνος ηλεκτροπληξίας.
<table align="center">
 <tr>
  <td></td>
  <td></td>
  <td></td>   
 </tr>
</table>
<table align="center">
 <tr>
  <td>
  </td>
  <td>
  </td> 
  </tr>
</table>
<table align="center">
 <tr>
  <td></td>
  <td></td>  
 </tr>
</table>
<H3>Πέρασμα σωλήνων και καλωδίων και τελική τοποθέτηση της μονάδας</H3>
Πάλι με την βοήθεια του ηλεκτρολογικού τομέα, τοποθετήθηκαν τα λάστιχα και τα μπεκ στις ρίζες των φυτών και συνδέθηκαν οι αισθητήρες ώστε να γίνει η τελική δοκιμή.
Η μονάδα σε λειτουργία στο αίθριο του Ε.Κ. Πρέβεζας.
<p align = "center">
  
</p>
<H3>Παρουσίαση της λειτουργίας του υποσυστήματος 1</H3>
Στον εσωτερικό κήπο του Ε.Κ. δοκιμάσαμε το σύστημα εξοικονόμησης νερού. Στα ακόλουθα video ο μαθητής παρουσιάζει την λειτουργία του.
<table align="center">
 <tr>
  <td>
  </td>
  <td>
  </td>
  </tr>
  <tr align="center">
    <td><sub><sup>Παρουσίαση τοπικής διαχείρισης μέσω Web Interface</sup></sub></td>
    <td><sub><sup>Παρουσίαση κεντρικής διαχείρισης μέσω Node Red</sup></sub></td>
  </tr>
</table>

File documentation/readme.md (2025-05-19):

Εδώ υπάρχουν όλα τα αρχεία περιγραφής του έργου.

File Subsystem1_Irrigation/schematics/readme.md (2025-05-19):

Τα θεωρητικά κυκλώματα του συστήματος εξοικονόμησης νερού και του προγραμματιστή του αρθρώματος ESP-01.

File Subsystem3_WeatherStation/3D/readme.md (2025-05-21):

Αρχεία για εκτύπωση στον εκτυπωτή 3D των μετεωρολογικών οργάνων.

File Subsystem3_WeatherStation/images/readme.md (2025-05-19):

Φωτογραφίες από τα στάδια κατασκευής του μετεωρολογικού σταθμού.

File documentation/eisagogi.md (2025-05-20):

<H2>Γενικές πληροφορίες</H2>
<p>Στην ενότητα αυτή θα αναφέρουμε γενικές πληροφορίες σχετικά με την υλοποίηση του έργου. Τα τρία υποσυστήματα παρουσιάζουν πολλές ομοιότητες τόσο στο υλικό όσο και στο λογισμικό. Και τα τρια βασίζονται σε ένα κοινό σχέδιο με μικρές παραλαγές ανάλογα με την μονάδα. Και στο λογισμικό υπάρχει η ίδια λογική, δηλαδή το ίδιο πρόγραμμα με παραλλαγές στην παρουσίαση των δεδομένων και την επικοινωνία με τους αισθητήρες - ενεργοποιητές.</p>

<p>Και οι τρεις μονάδες διαθέτουν από δύο μικροελεγκτές. Έναν 8 bit τύπου AVR (Arduino Nano) με πολλούς ακροδέκτες εισόδου / εξόδου, ο οποίος λειτουργεί ως expander και επικοινωνεί με τους αισθητήρες, όργανα ή ενεργοποιητές που διαφέρουν από μονάδα σε μονάδα. Έναν 32 bit τύπου ESP8266 με 1Mbyte μνήμη Flash (ESP-01). Αυτός είναι πολύ πιο ισχυρός διαθέτει ελάχιστους ακροδέκτες εισόδου / εξόδου. Οι δύο ελεγκτές επικοινωνούν μέσω σειριακής θύρας. </p>

<p>Στην πραγματικότητα ο δεύτερος αναλαμβάνει τον μεγαλύτερο φόρτο εργασίας και εκτελεί τα ακόλουθα καθήκοντα:
<ol>
<li>Λαμβάνει μηνύματα από τον AVR σε τακτά χρονικά διαστήματα (κάθε 1sec) με τις τιμές των αισθητήρων ή των οργάνων.</li>
<li>Αν πάρει εντολή από τον Node Red server ή το Web Interface, άμεσα την μεταβιβάζει στον AVR expander ώστε να στείλει σήματα στους ενεργοποιητές (Relays, Servos κλπ).</li>
<li>Αναλαμβάνει την επικοινωνία μέσω WiFi με το οικίο Access Point αλλά μπορεί να λειτουργήσει και ο ίδιος σαν AP ώστε να γίνουν οι αρχικές ρυθμίσεις σύνδεσης.</li>
<li>Λειτουργεί ολοκληρωμένος TCP/IP stack για την επικοινωνία με το διαδίκτυο.</li>
<li>Λειτουργεί mini Web Server για τον χειρισμό αλλά και τις αρχικές ρυθμίσεις των μονάδων.</li>
<li>Λειτουργεί mqtt client ώστε να στέλνει και να λαμβάνει μηνύματα από τον οικείο broker. Η περίοδος αποστολής είναι ρυθμιζόμενη από 0,5 - 10 λεπτά.</li>
<li>Κρατάει αρχεία καταγραφής με τις μετρήσεις και τις ενέργειες που έγιναν.</li>
<li>Έχει ακριβή χρόνο NTP από το διαδίκτυο.</li>
</ol>
</p>

Για τον προγραμματισμό των αρθρωμάτων ESP-01 χρησιμοποιήσαμε αυτόν τον προγραμματιστή:
<p align = "center">
  
</p>

<p align = "center">
  
</p>

<p>
  Στο αρχείο pltformio.ini περιγράφεται και το σχήμα διαμόρφωσης της μνήμης Flash 1Mbyte. Η μνήμη χωρίζεται σε δύο blocks των 512Kbyte. Το 1ο καταλαμβάνεται από τον κώδικα που φτάνει στο 73-75% ενώ το δεύτερο διαμορφώνεται με το σύστημα αρχείων LittleFs. Εκεί αποθηκεύονται οι σελίδες HTML, τα αρχεία CSS και JavaScript καθώς και τα αρχεία ρυθμίσεων και καταγραφής. 
</p>

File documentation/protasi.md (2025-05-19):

Στόχοι
========================
Η ομάδα μας στα πλαίσια του <a href="https://openedtech.ellak.gr/">7ου Πανελλήνιου Διαγωνισμού Ανοιχτών Τεχνολογιών στην Εκπαίδευση</a> ο οποίος διοργανώνεται από τον <a href="https://eellak.ellak.gr/">ΕΕΛΛΑΚ</a> και με θεματική ενότητα <b>"Ανοιχτή Σχεδίαση για έναν Άμεσο Δημόσιο Χώρο"</b> πρόκειται να υλοποιήσει ένα σύστημα εποπτείας και διαχείρισης ενέργειας και νερού για το σχολείο μας. Το σύστημα θα τοποθετηθεί στους χώρους του εργαστηριακού κέντρου (Ε.Κ.) και θα λειτουργήσει σε μικρή κλίμακα. 

Συγκεκριμένα το σύστημα θα δομηθεί στους τέσσερις ακόλουθους άξονες:

<H3>Α. Εξοικονόμηση νερού</H3>
Θα σχεδιάσουμε και θα κατασκευάσουμε μονάδα αυτόματου ποτίσματος με αισθητήρες υγρασίας και θερμοκρασίας στην ρίζα των φυτών ώστε να ποτίζονται αυτόματα μόνο όταν είναι απαραίτητο. Θα κατασκευάσουμε τουλάχιστον δύο μονάδες οι οποίες θα τοποθετηθούν στον κήπο του σχολείου. Οι μονάδες αυτές θα επικοινωνούν μέσω διαδικτύου με το κεντρικό σύστημα διαχείρησης. <a href = "/resources/images/A_Water.png">Αρχικό διάγραμμα μονάδας</a>.

<H3>Β. Εξοικονόμηση ενέργειας</H3>
Θα σχεδιάσουμε και θα κατασκευάσουμε μονάδα εποπτείας και ελέγχου σε μια γραμμή φωτισμού για τον κήπο του σχολείου. Η μονάδα θα μετράει συνεχώς την κατανάλωση ενέργειας της γραμμής και θα ανάβει μόνο τα απαραίτητα φώτα ανάλογα με το φως ημέρας. Η μονάδα θα επικοινωνεί μέσω διαδικτύου με το κεντρικό σύστημα διαχείρισης. <a href = "/resources/images/B_Power.png">Αρχικό διάγραμμα μονάδας</a>

<H3>Γ. Μετεωρολογικός σταθμός</H3>
Θα σχεδιάσουμε έναν μετεωρολογικό σταθμό ο οποίος θα επικοινωνεί μέσω διαδικτύου με τον κεντρικό σύστημα διαχείρισης ώστε τα δεδομένα να χρησιμοποιούνται από τις προηγούμενες μονάδες. Τα περισσότερα όργανα του μετεωρολογικού σταθμού θα τα κατασκευάσουμε στον εκτυπωτή 3D του σχολείου. <a href = "/resources/images/C_MeteoStation.png">Αρχικό διάγραμμα μονάδας</a>

<H3>Δ. Κεντρικό σύστημα διαχείρισης</H3>
Αυτό θα είναι το σύστημα συλλογής και καταγραφής δεδομένων από τις προηγούμενες μονάδες. Θα υλοποιηθεί με το λογισμικό ανοιχτού κώδικα Node RED το οποίο θα εγκατασταθεί σε έναν διακομιστή του σχολείου μας. 
<br>
<p align = "center">

</p>

Οι εκπαιδευτικοί στόχοι είναι οι ακόλουθοι:
1. Οι μαθητές να ασχοληθούν με τον σχεδιασμό και την υλοποίηση ενός πραγματικού έργου.
2. Θα γνωρίσουν όλα τα στάδια υλοποίησης ενός έργου όπως σχεδιασμός, κατασκευή, προγραμματισμός, βαθμονόμηση, δοκιμές.
3. Θα μάθουν να εργάζονται ως ομάδα στην οποία το κάθε μέλος θα έχει διαφορετικές αρμοδιότητες.
4. Θα εμβαθύνουν στην μετεωρολογία και θα κατανοούν καλύτερα τα καιρικά φαινόμενα.
5. Θα ευαισθητοποιηθούν στην εξοικονόμηση ενέργειας και νερού.
6. Θα σκεφτούν τρόπους βαθμονόμησης των οργάνων εφόσον τα περισσότερα θα κατασκευαστούν από αυτούς.
7. Θα γνωρίσουν την χαρά της δημιουργίας.

Είμαστε μαθητές του τομέα πληροφορικής και ηλεκτρολογίας του 1ου ΕΠΑ.Λ. Πρέβεζας. Το έργο πρόκειται να υλοποιηθεί στα εργαστήρια του Ε.Κ. Πρέβεζας εκτός διδακτικού ωραρίου.

Υλικά
=====

<H3>A. Μονάδες αυτόματου ποτίσματος (2 τεμάχια)</H3>

<center>

| Α/Α | Περιγραφή |  Τιμή μον. | Ποσότ. | Μερικό Σύνολο |
|:---:|:---:|:---:|:---:| ---:|
| 1 | Arduino Nano | 7€ | 2 | 14€ |
| 2 | Θερμόμετρο εξ. χώρου DS18B20 | 4€ | 2 | 8€ |
| 3 | Module WiFi ESP8266-01 | 4€ | 2 | 8€ |
| 4 | Servo Motor MG996R | 7€ | 2 | 14€ |
| 5 | Πλακέτα Perfboard 12x18 | 4€ | 2 | 8€ |
| 6 | Κουτί Ηλ/κό αδιάβροχο | 8€ | 2 | 16€ |
| 7 | DC-DC Converter | 4€ | 2 | 8€ |
| 8 | Liquid Flow Sensor | 11€ | 1 | 11€ |
| 9 | Αισθητήρας υγρασίας εδάφους (capacitive) | 7€ | 2 | 14€ |
|10 | Βίδες, καλώδια, λοιπά εξαρτήματα | 15€ | 1 | 15€ |
| |||**Σύνολο:** |  **116€** | 

</center>

<H3>Β. Μονάδα διαχείρισης ενέργειας</H3>

<center>

| Α/Α | Περιγραφή |  Τιμή μον. | Ποσότ. | Μερικό Σύνολο |
|:---:|:---:|:---:|:---:| ---:|
| 1 | Arduino Nano | 7€ | 1 | 7€ |
| 2 | Module WiFi ESP8266-01 | 4€ | 1 | 4€ |
| 3 | Πλακέτα Perfboard 12x18 | 4€ | 1 | 4€ |
| 4 | Κουτί Ηλ/κό αδιάβροχο | 8€ | 1 | 8€ |
| 5 | DC-DC Converter | 4€ | 1 | 4€ |
| 6 | Αισθητήρας ρεύματος | 10€ | 1 | 10€ |
| 7 | Ηλεκτρονόμοι (220v/2A) Relays | 3€ | 4 | 12€ |
| 8 | Βίδες, καλώδια, λοιπά εξαρτήματα | 10€ | 1 | 10€ |
| |||**Σύνολο:** |  **59€** | 

</center>

<H3>Γ. Μετεωρολογικός σταθμός</H3>

<center>

| Α/Α | Περιγραφή |  Τιμή μον. | Ποσότ. | Μερικό Σύνολο |
|:---:|:---:|:---:|:---:| ---:|
| 1 | Arduino Nano | 7€ | 1 | 7€ |
| 2 | Module WiFi ESP8266-01 | 4€ | 1 | 4€ |
| 3 | Πλακέτα Perfboard 12x18 | 4€ | 1 | 4€ |
| 4 | Κουτί Ηλ/κό αδιάβροχο | 8€ | 1 | 8€ |
| 5 | DC-DC Converter | 4€ | 1 | 4€ |
| 6 | TCRT5000 | | 7 | 12€ |
| 7 | BME280 | 17€ | 1 | 17€ |
| 8 | Βίδες, καλώδια, λοιπά εξαρτήματα | 10€ | 1 | 10€ |
| |||**Σύνολο:** |  **66€** | 

</center>

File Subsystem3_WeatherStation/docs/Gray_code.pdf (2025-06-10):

Φύλλο1

Σελίδα 1

## Τροποποιημένος κώδικας Gray (Οι θέσεις 0 και 31 δεν χρησιμοποιούνται)

Ταξινόμηση σύμφωνα με την θέση του δίσκου

Α/Α | Gray Code Binary | Dec | Μοίρες | Α/Α | Gray Code Binary | Dec | Μοίρες
1 | 00000 | 0 | | 1 | 00000 | 0
2 | 00001 | 1 | 0 | 2 | 00001 | 1 | 0
3 | 00011 | 3 | 12 | 3 | 00010 | 2 | 72
4 | 01011 | 11 | 24 | 4 | 00011 | 3 | 12
5 | 11011 | 27 | 36 | 5 | 00100 | 4 | 144
6 | 10011 | 19 | 48 | 6 | 00101 | 5 | 132
7 | 10010 | 18 | 60 | 7 | 00110 | 6 | 84
8 | 00010 | 2 | 72 | 8 | 00111 | 7 | 120
9 | 00110 | 6 | 84 | 9 | 01000 | 8 | 216
10 | 10110 | 22 | 96 | 10 | 01001 | 9 | 348
11 | 10111 | 23 | 108 | 11 | 01010 | 10 | 204
12 | 00111 | 7 | 120 | 12 | 01011 | 11 | 24
13 | 00101 | 5 | 132 | 13 | 01100 | 12 | 156
14 | 00100 | 4 | 144 | 14 | 01101 | 13 | 168
15 | 01100 | 12 | 156 | 15 | 01110 | 14 | 192
16 | 01101 | 13 | 168 | 16 | 01111 | 15 | 180
17 | 01111 | 15 | 180 | 17 | 10000 | 16 | 288
18 | 01110 | 14 | 192 | 18 | 10001 | 17 | 300
19 | 01010 | 10 | 204 | 19 | 10010 | 18 | 60
20 | 01000 | 8 | 216 | 20 | 10011 | 19 | 48
21 | 11000 | 24 | 228 | 21 | 10100 | 20 | 276
22 | 11010 | 26 | 240 | 22 | 10101 | 21 | 312
23 | 11110 | 30 | 252 | 23 | 10110 | 22 | 96
24 | 11100 | 28 | 264 | 24 | 10111 | 23 | 108
25 | 10100 | 20 | 276 | 25 | 11000 | 24 | 228
26 | 10000 | 16 | 288 | 26 | 11001 | 25 | 336
27 | 10001 | 17 | 300 | 27 | 11010 | 26 | 240
28 | 10101 | 21 | 312 | 28 | 11011 | 27 | 36
29 | 11101 | 29 | 324 | 29 | 11100 | 28 | 264
30 | 11001 | 25 | 336 | 30 | 11101 | 29 | 324
31 | 01001 | 9 | 348 | 31 | 11110 | 30 | 252
32 | 11111 | 31 | | 32 | 11111 | 31

Ταξινόμηση σύμφωνα με την γωνία

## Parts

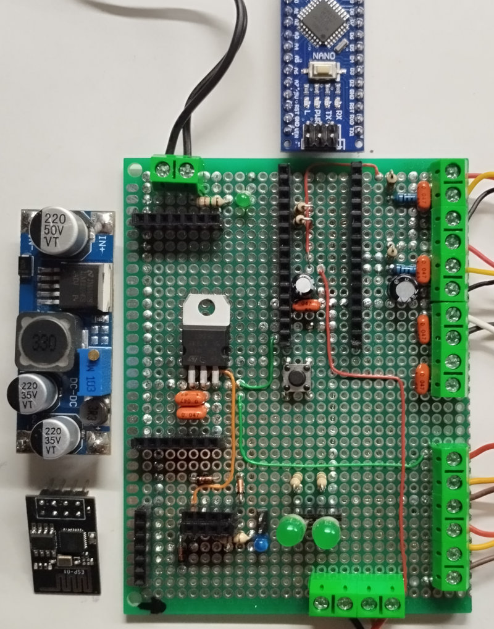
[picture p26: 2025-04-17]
Subsystem1_Irrigation/Images/EEKYP1_pcbParts.jpg

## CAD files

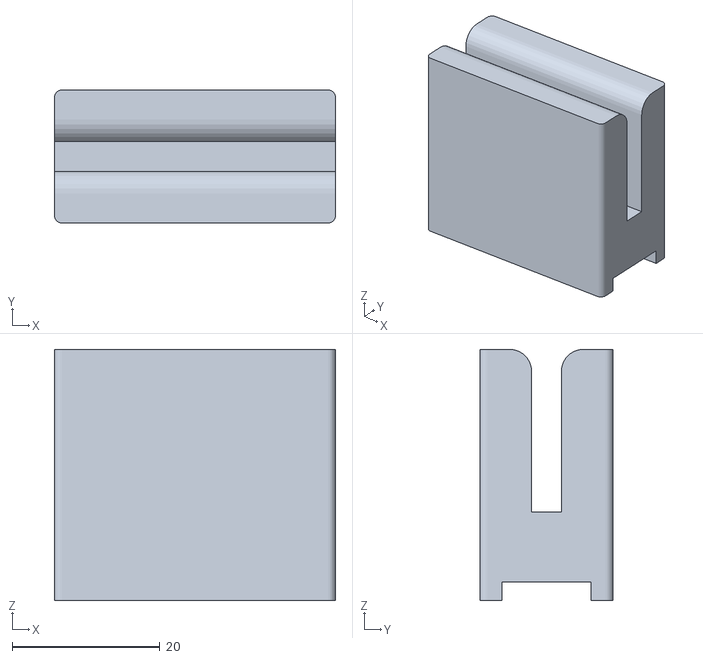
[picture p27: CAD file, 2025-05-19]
Subsystem1_Irrigation/3D/Valve_Rotor.stl
38.0 x 18.0 x 34.0

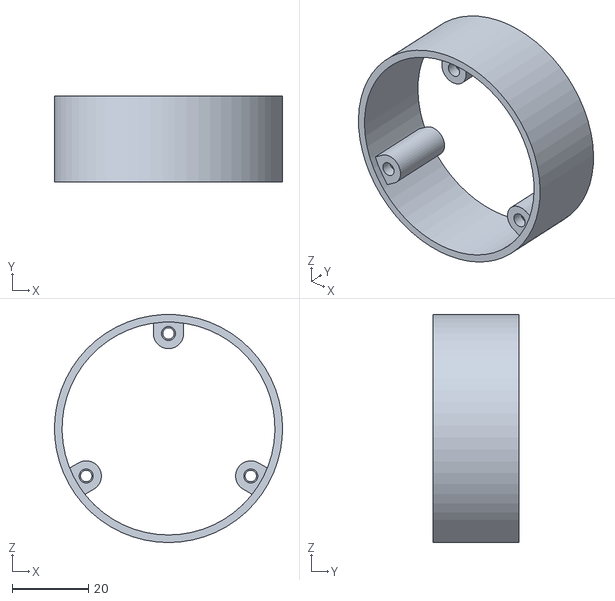
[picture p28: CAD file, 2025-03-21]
Subsystem3_WeatherStation/3D/Anemometer - 41367/files/body.STL
60.0 x 22.6 x 60.0

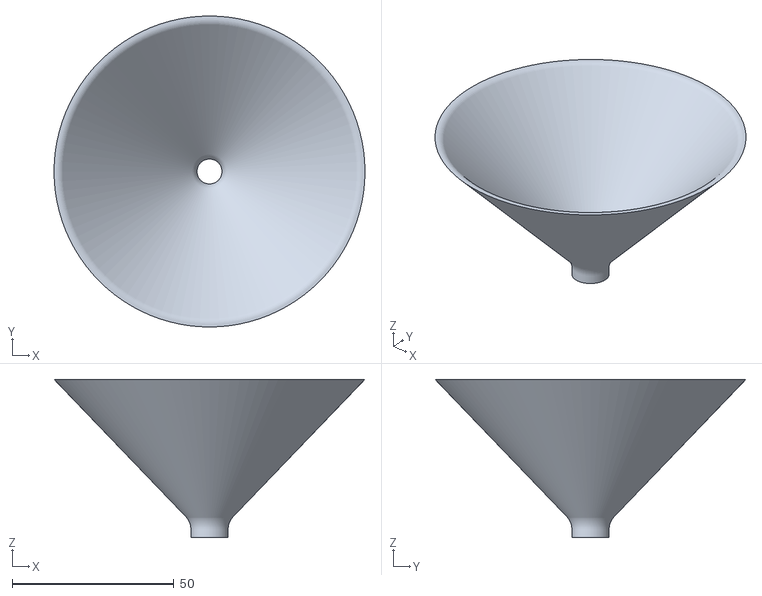
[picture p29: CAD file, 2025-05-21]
Subsystem3_WeatherStation/3D/Rainfall meter _ Rain gauge/files/rainfall-meter-funnel.stl
96.0 x 96.0 x 48.8

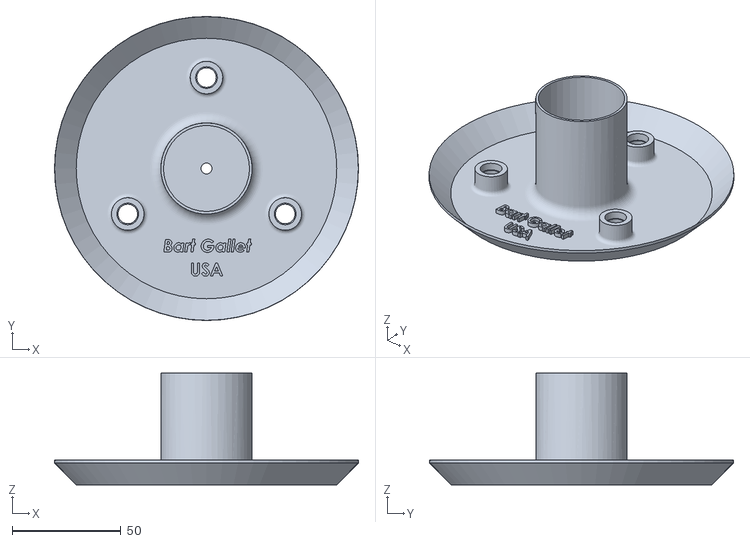
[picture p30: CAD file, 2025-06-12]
Subsystem3_WeatherStation/3D/Stevenson screen/files/Bottom_part.STL
140.0 x 140.0 x 51.4

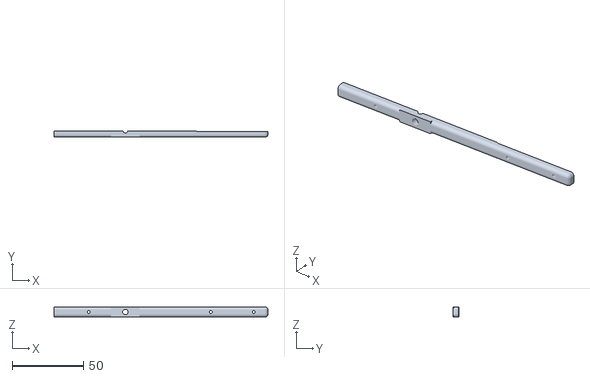
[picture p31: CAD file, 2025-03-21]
Subsystem3_WeatherStation/3D/Wind_vane/7_rod(x2).STL
150.0 x 4.50 x 7.00

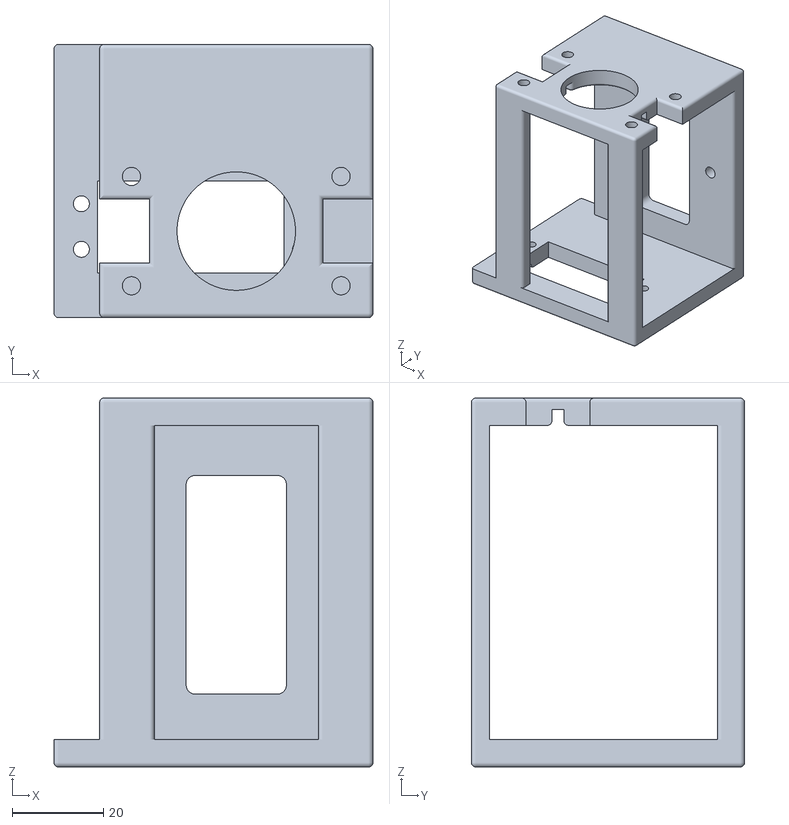
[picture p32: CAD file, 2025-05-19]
Subsystem1_Irrigation/3D/Valve_Body.stl
70.0 x 60.0 x 81.0

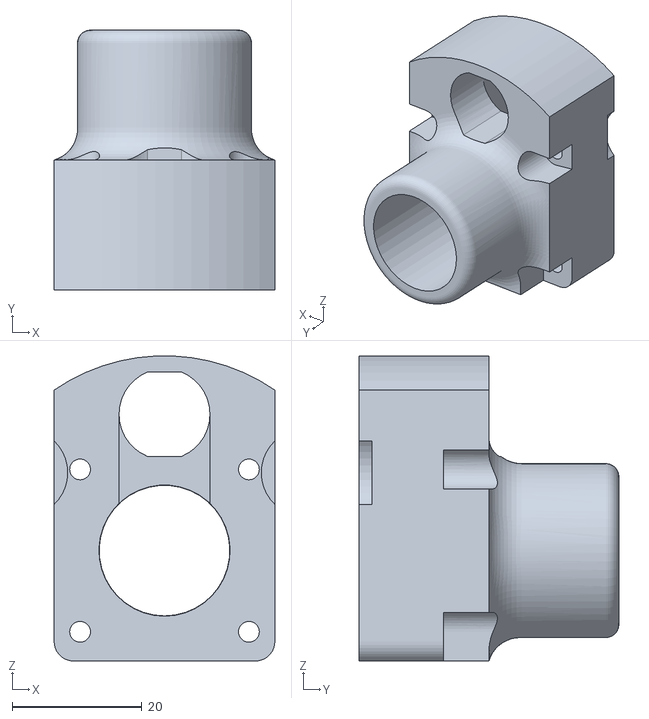
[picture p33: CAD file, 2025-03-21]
Subsystem3_WeatherStation/3D/Anemometer - 41367/files/support.STL
34.0 x 40.0 x 47.0

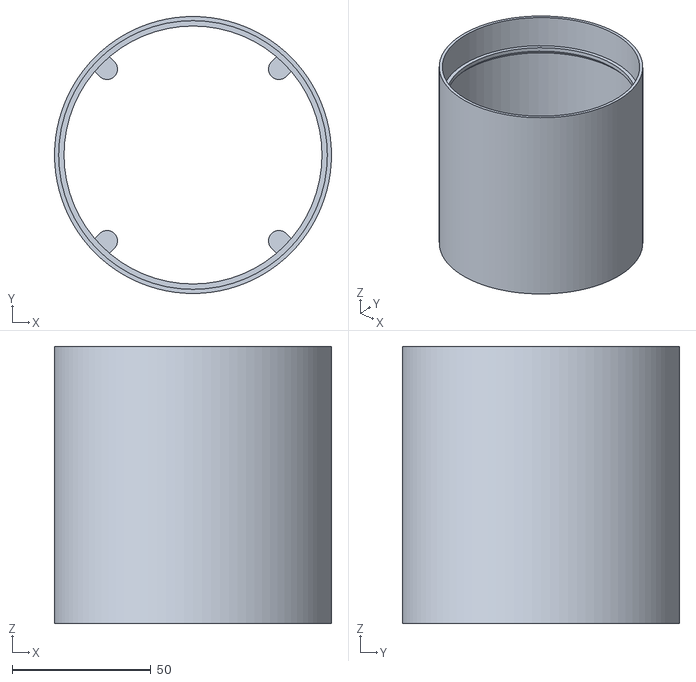
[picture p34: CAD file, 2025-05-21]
Subsystem3_WeatherStation/3D/Rainfall meter _ Rain gauge/files/rainfall-meter-top-case.stl
100.0 x 100.0 x 100.0

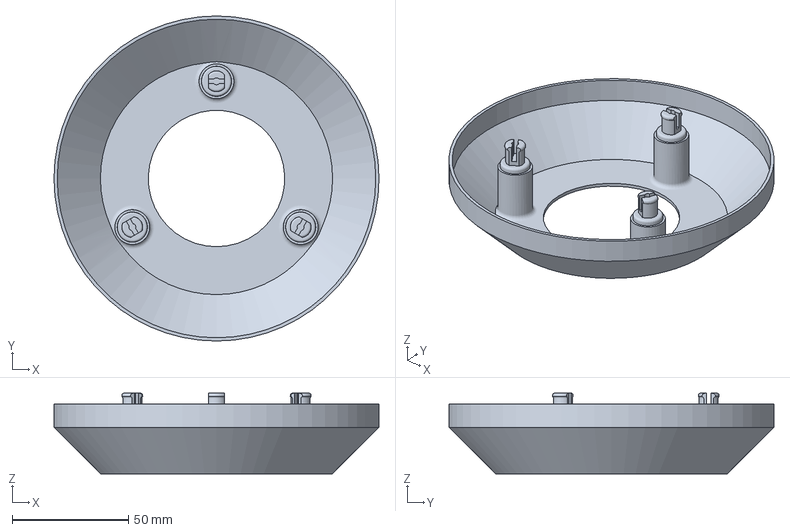
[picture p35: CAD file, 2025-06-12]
Subsystem3_WeatherStation/3D/Stevenson screen/files/Middle_part.3mf
140.0 x 140.0 x 34.8 mm

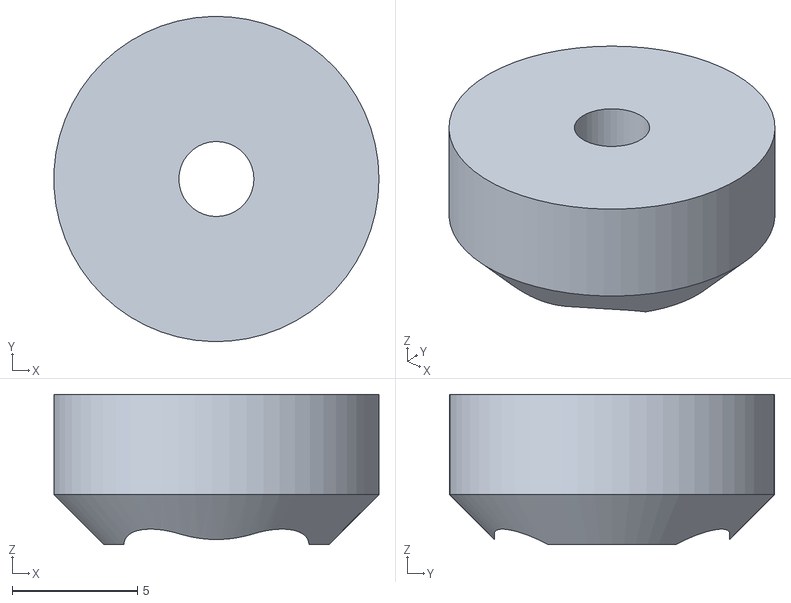
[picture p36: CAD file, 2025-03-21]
Subsystem3_WeatherStation/3D/Wind_vane/6_noze_ring.STL
13.0 x 13.0 x 6.00

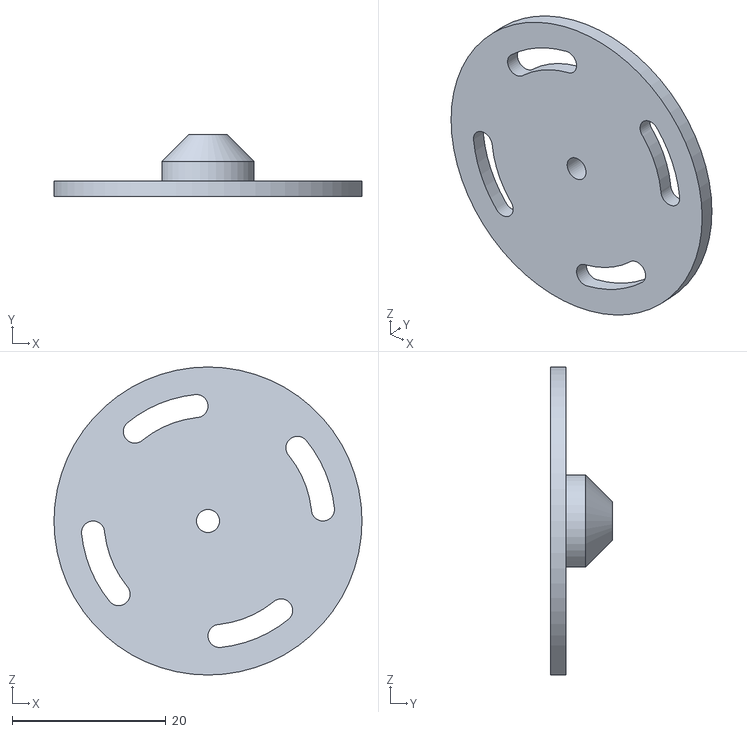
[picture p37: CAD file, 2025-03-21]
Subsystem3_WeatherStation/3D/Anemometer - 41367/files/sensor_wheel.STL
40.0 x 8.00 x 40.0

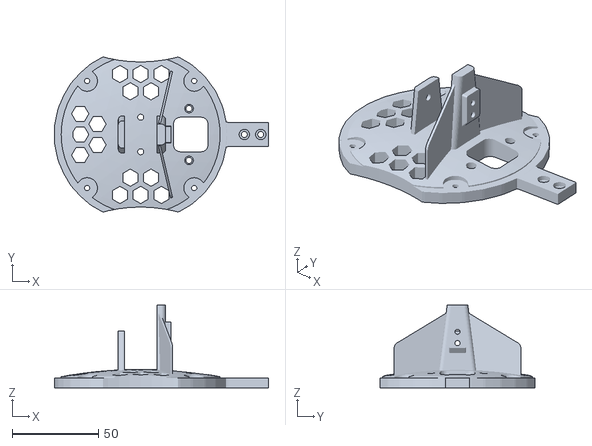
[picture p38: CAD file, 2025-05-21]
Subsystem3_WeatherStation/3D/Rainfall meter _ Rain gauge/files/rainfall-meter-base.stl
123.9 x 89.9 x 48.0

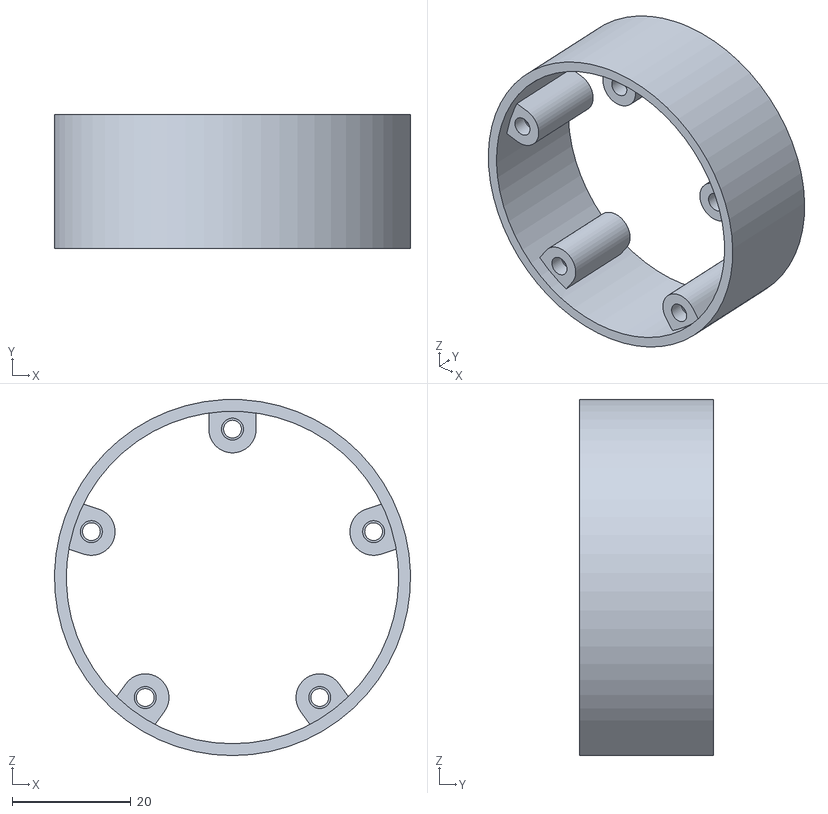
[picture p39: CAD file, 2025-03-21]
Subsystem3_WeatherStation/3D/Wind_vane/1_body.STL
60.0 x 22.6 x 60.0

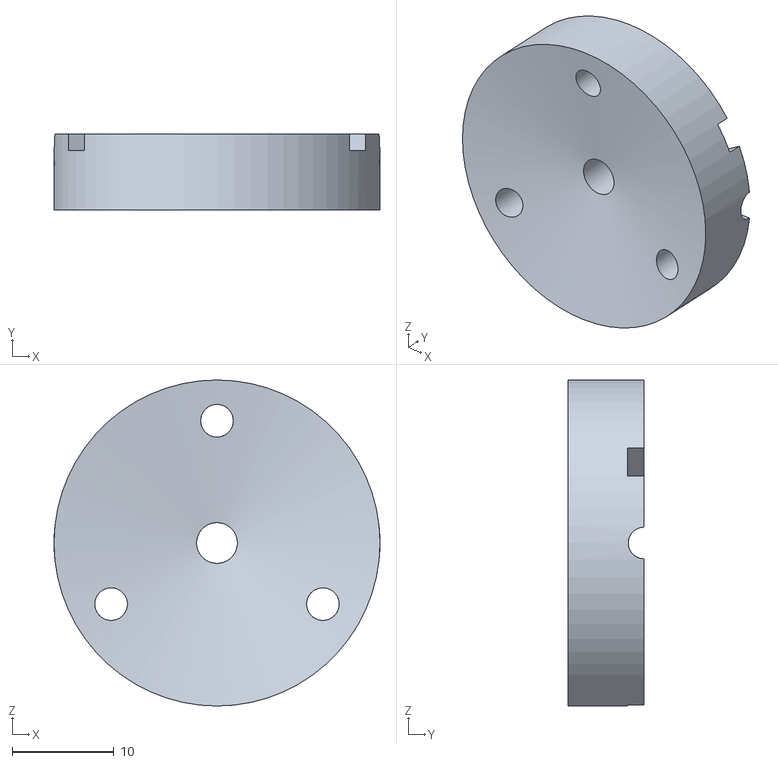
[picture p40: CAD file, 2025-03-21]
Subsystem3_WeatherStation/3D/Anemometer - 41367/files/rotor_part2.STL
32.0 x 7.47 x 32.0

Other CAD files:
Subsystem3_WeatherStation/3D/Rainfall meter _ Rain gauge/files/pole-holder.stl
Subsystem3_WeatherStation/3D/Wind_vane/8_led_holder(x2).STL
Subsystem3_WeatherStation/3D/Anemometer - 41367/files/body_bottom.STL
Subsystem3_WeatherStation/3D/Rainfall meter _ Rain gauge/files/rainfall-meter-bucket-mag.stl
Subsystem3_WeatherStation/3D/Anemometer - 41367/files/body_top.STL
Subsystem3_WeatherStation/3D/Anemometer - 41367/files/cupx3.STL
Subsystem3_WeatherStation/3D/Anemometer - 41367/files/led_holderx2.STL
Subsystem3_WeatherStation/3D/Anemometer - 41367/files/rotor_lockx2.STL
Subsystem3_WeatherStation/3D/Anemometer - 41367/files/rotor_part1.STL
Subsystem3_WeatherStation/3D/Wind_vane/10_hub_bottom.STL
Subsystem3_WeatherStation/3D/Wind_vane/2_body_top.STL
Subsystem3_WeatherStation/3D/Wind_vane/3_body_bottom.STL
Subsystem3_WeatherStation/3D/Wind_vane/4_wheel.STL
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

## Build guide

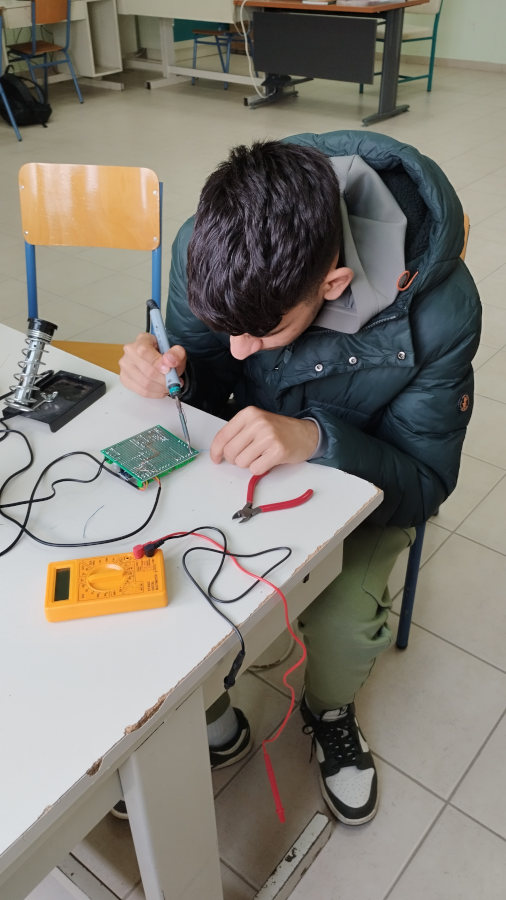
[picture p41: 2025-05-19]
Subsystem1_Irrigation/Images/EEKYP1_pcb_construction3.jpg

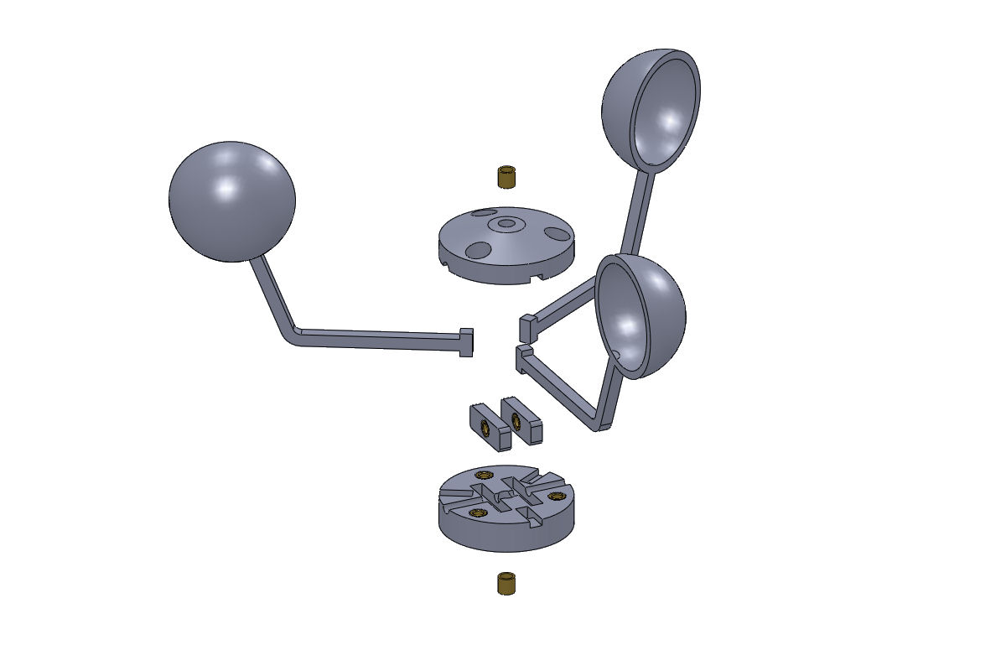
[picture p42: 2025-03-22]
Subsystem3_WeatherStation/images/anemometer_rotor_assembly_big.jpg

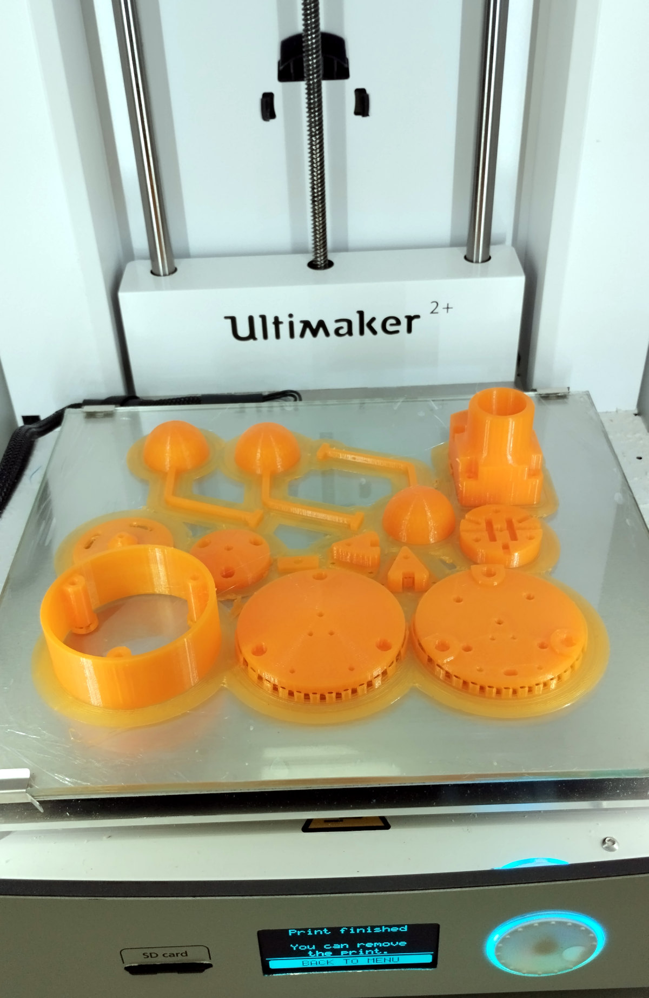
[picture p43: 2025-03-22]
Subsystem3_WeatherStation/images/print_anemometer.jpg

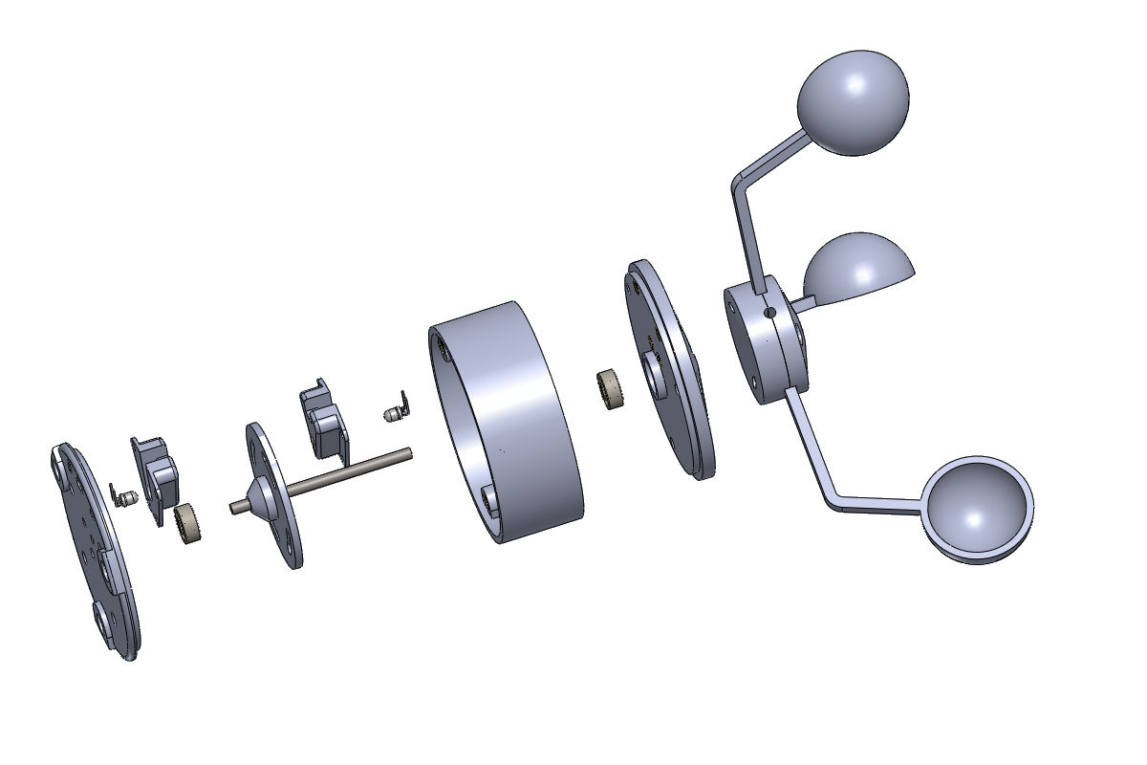
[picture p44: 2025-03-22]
Subsystem3_WeatherStation/images/anemometer_body_assembly_big.jpg

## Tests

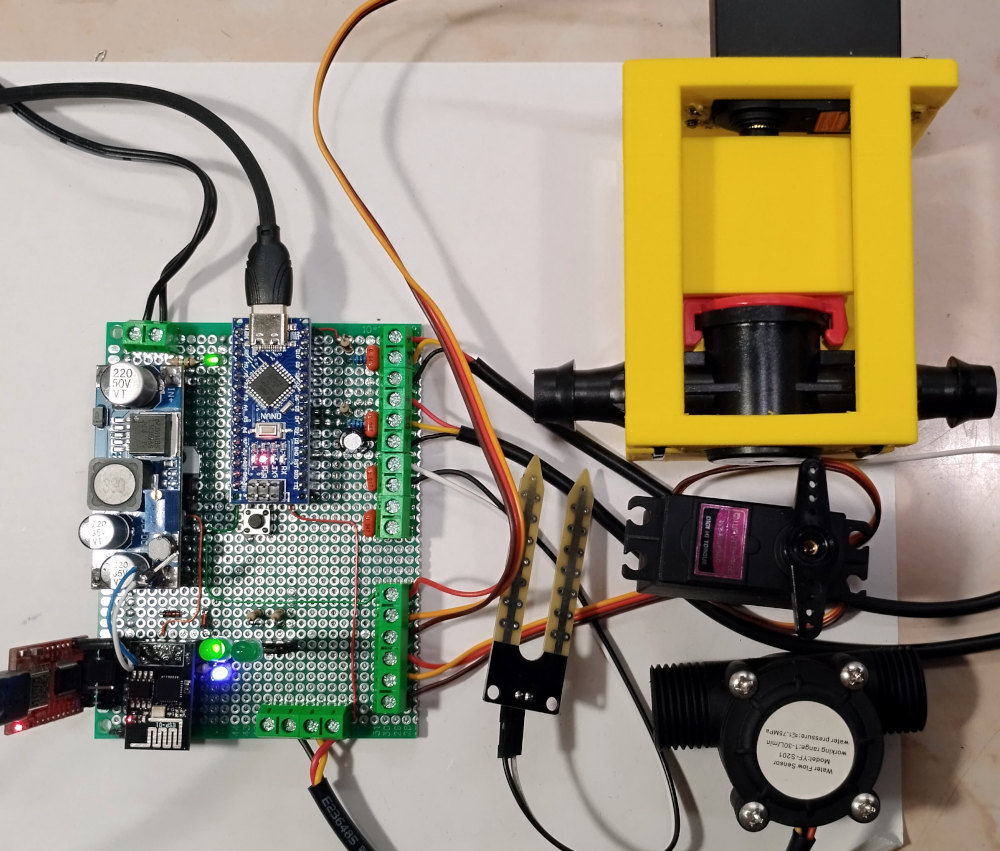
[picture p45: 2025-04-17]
Subsystem1_Irrigation/Images/EEKYP1_test.jpg

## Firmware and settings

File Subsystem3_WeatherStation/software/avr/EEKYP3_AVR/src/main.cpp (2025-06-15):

#include <Arduino.h>
#include <avr/pgmspace.h>
#include <avr/wdt.h>
#include <SoftwareSerial.h>

#include "definitions.h"
#include "sensors.h"
#include "functions.h"
#include "cmd.h"
#include "commands.h"
#include "buttons.h"

unsigned long airp, rainp;
int UVanalog_val, air_dir, irradiation;
float UVsensor_val, pressure, temp1, temp2, humidity, air_speed, Vline;

//I.S.R. 1
void air_pulse () // Interrupt function
 {
  noInterrupts();
  airp++;
  interrupts();
 }

//I.S.R. 2
void rain_pulse () // Interrupt function
 {
  noInterrupts();
  rainp++;
  interrupts();
 }

void setup() 
 {
  pinMode(LED_BUILTIN, OUTPUT);
  pinMode(AIR_SPEED, INPUT_PULLUP);
  pinMode(RAIN_FALL, INPUT_PULLUP);
  pinMode(AIR_DIR_B0, INPUT);
  pinMode(AIR_DIR_B1, INPUT);
  pinMode(AIR_DIR_B2, INPUT);
  pinMode(AIR_DIR_B3, INPUT);
  pinMode(AIR_DIR_B4, INPUT);
  SetupButtons();
  Serial.begin(9600);
  cmdInit(9600);
  while (!Serial);        //Περίμενε
  Serial.println(F("***** EEKYP - WEATHER STATION (c)2025 [1o EPAL PREVEZAS - EK PREVEZAS] *****"));
  Serial1.begin(9600);
  dht.begin(); //Αρχικοποίησε το DHT11
  init_bmp280(); //Αρχικοποίησε το BMP280
  #ifdef USE_VEML6075
  init_VEML6075();
  #endif
  attachInterrupt(0, air_pulse, RISING);
  attachInterrupt(1, rain_pulse, FALLING);
  init_commands(); //Αρχικοποίησε εντολές για την σειριακή γραμμή εντολών
  interval1 = millis();
 }

void loop() 
 {
  but_prog.CheckBP();
  cmdPoll(); //Έλεγξε για εντολή στην κονσόλα
  
  if ((millis() - interval1) > AQUIRE_MS)
     {
      //Υπολογισμός δείκτη UV  
      #ifndef USE_VEML6075 //Αναλογικός αισθητήρας
      UVanalog_val = analogRead(UV_Pin); //Διάβασε αναλογική τιμή
      //Serial.println(UVanalog_val);
      if (UVanalog_val < 20) 
          UVsensor_val = 0;
      else
          UVsensor_val = 0.05 * UVanalog_val - 1;
      #else
      UVsensor_val = uv.readUVI(); //Ψηφιακός αισθητήρας IIC VEML6075
      #endif
      //Υπολογισμός ταχύτητας ανέμου
      air_speed = (float)airp;
      airp = 0;
      //Διάβασμα ύψους βροχής
      //Είναι οι παλμοί rainp
      //Διάβασμα θερμοκρασίας 1 από το BMP280
      temp1 = bmp.readTemperature();
      //Διάβασμα ατμοσφαιρικής πίεσης από το BMP280
      pressure = bmp.readPressure() / 100; //Διαίρεση με 100 επειδή ο αισθητήρας μετράει σε Pascal
      //Διάβασμα υγρασίας από το DHT11
      humidity = dht.readHumidity();
      //Διάβασμα θερμοκρασίας 2 από το DHT11
      temp2 = dht.readTemperature(); //default σε °C
      temp2 -= 2.5;
      //Διάβασμα κατεύθυνσης ανέμου
      air_dir = readAirVane();
      //Υπολογισμός τάσης γραμμής
      Vline = analogRead(V_LINE_Pin) * (float) QUANT * DIV_RATIO * 1.025; //Συντελεστής διόρθωσης το 1.025
      //Διάβασμα ηλιακής ακτινοβολίας
      irradiation = analogRead(IRRAD_Pin); //Στέλνει ακέραια τιμή του ADC, ο υπολογισμός γίνεται στο ESP
      
      #if DEBUG_INFO
      Serial.println(F("========================================"));
      Serial.print(F("UV Index: ")); Serial.println(UVsensor_val);
      Serial.print(F("Air speed = ")); Serial.println(air_speed);
      Serial.print(F("Rain pulses = ")); Serial.println(rainp);
      Serial.print(F("Temper1 = ")); Serial.print(temp1); Serial.println(" °C");
      Serial.print(F("Pressure = ")); Serial.print(pressure); Serial.println(" hPa");
      Serial.print(F("Humidity = ")); Serial.print(humidity); Serial.println(" %");
      Serial.print(F("Temper2 = ")); Serial.print(temp2); Serial.println(" °C");
      Serial.print(F("Air angle = ")); Serial.println(air_dir);
      Serial.print(F("Vline: ")); Serial.println(Vline);
      #endif

      //Προετοιμασία μηνύματος με τιμές χωρισμένες με κενά
      char tmp[70], air_speed_cstr[6], temp1_cstr[6], temp2_cstr[6], pressure_cstr[8], humidity_cstr[6], vline_cstr[5], uvidx_cstr[5];
      dtostrf(air_speed, 2, 1, air_speed_cstr); dtostrf(temp1, 2, 1, temp1_cstr);
      dtostrf(temp2, 2, 1, temp2_cstr); dtostrf(pressure, 4, 1, pressure_cstr); dtostrf(humidity, 2, 1, humidity_cstr);
      dtostrf(Vline, 2, 1, vline_cstr); dtostrf(UVsensor_val, 2, 1, uvidx_cstr);
      sprintf(tmp,"s_raw %s %s %s %s %d %ld %s %s %d %s", temp1_cstr, pressure_cstr, humidity_cstr, air_speed_cstr, air_dir, rainp, uvidx_cstr, temp2_cstr, irradiation, vline_cstr);
      //Serial.println(tmp); //Debug
      
      if (Serial1.available() == 0)
          Serial1.println(tmp);
      interval1 = millis();
     }
 }

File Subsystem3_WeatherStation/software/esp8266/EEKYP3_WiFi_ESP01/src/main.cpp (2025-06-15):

#pragma GCC diagnostic ignored "-Wunused-but-set-variable"
#pragma GCC diagnostic ignored "-Wunused-function"
#include <Arduino.h>
#include <PubSubClient.h>
#include <LittleFS.h>
#include "definitions.h"
#include "functions.h"
#include "network.h"
#include "commands.h"

//Ορισμός Timer
static os_timer_t intervalTimer;
static os_timer_t mqttTimer;

byte five_secs;    //Μετρητής σε sec που μετράει αντίστροφα μέχρι το 0.
unsigned long interval = 0;

void setup() 
{
 pinMode(BUILTIN_LED, OUTPUT); //pin 2
 Serial.begin(9600);
 delay(200);
 #if DEBUG_INFO
 Serial.println(F("\n\nEEKYP Weather Station WiFi Module (c)2025 Stavros S. Fotoglou - E.K. Prevezas"));
 #endif
 //Προετοιμασία συστήματος αρχείων 256 Kbyte
 if (!LittleFS.begin()) 
    {
     #if DEBUG_INFO
     Serial.println(F("LittleFS initialisation failed!"));
     #endif
     while (1) yield(); // Stay here twiddling thumbs waiting
    }
 #if DEBUG_INFO
 Serial.println(F("\r\nLittleFS available!"));
 #endif
 LittleFS.begin();
 //Αν ξεκίνησε το σύστημα αρχείων στην εσωτερική Flash 4Mbyte
 //Εμφάνισε ελεύθερο χώρο από το σύστημα LittleFS
 FSInfo fs_info;
 LittleFS.info(fs_info);
 float fileTotalKB = (float)fs_info.totalBytes / 1024.0; 
 float fileUsedKB = (float)fs_info.usedBytes / 1024.0; 
 char tmp[40];
 sprintf(tmp, "Used %.1fKb of total %.1fKb", fileUsedKB, fileTotalKB);
 #if DEBUG_INFO
 Serial.println(tmp);
 #endif
 readSettings_net(); //Διάβασε ρυθμίσεις δικτύου από αρχείο
 //Ρουτίνα εξυπηρέτησης αν γίνει σύνδεση TCP με τον server π.χ. www.google.com 
 test_client->onConnect(&onConnect, test_client); //Στο network.h
 led_pat = 0b1000000000; //Αρχική κατάσταση
 initNetwork();  //Αρχικοποίηση δικτύου WiFi, IP, NTP και WebServer
 readSettings(); //Διάβασε ρυθμίσεις αρχικής οθόνης από SPIFFS και θέσε τις μεταβλητές λειτουργίας
 blink_per = millis();
 readSettings_wp(); //Διάβασε ρυθμίσεις λειτουργίας όπως ενέργειες βάσει των τιμών των αισθητήρων
 //Αρχική σύνδεση στον mqtt broker
 reconnect();
 five_secs = 5; //Κάθε 5 δευτερόλεπτα
 init_commands(); //Αρχικοποίησε εντολές για την σειριακή γραμμή εντολών
 //Κάθε 30 sec κάνε έλεγχο σύνδεσης
 os_timer_disarm(&intervalTimer); //Απενεργοποίηση Timer
 os_timer_setfn(&intervalTimer, &testcon, NULL); //Ορισμός ρουτίνας εξυπηρέτησης χωρίς ορίσματα στο network.h
 os_timer_arm(&intervalTimer, 30000, true);  //Ενεργοποίηση με επανάληψη κλήσης κάθε 30 sec
 //Κάθε 5 min κάνε έλεγχο σύνδεσης στον mqtt broker
 os_timer_disarm(&mqttTimer); //Απενεργοποίηση Timer
 os_timer_setfn(&mqttTimer, &pubmqtt, NULL); //Ορισμός ρουτίνας εξυπηρέτησης χωρίς ορίσματα στο network.h
 os_timer_arm(&mqttTimer, (unsigned long)(SetMQTT_Per.toFloat() * 60000), true);  //Ενεργοποίηση με επανάληψη κλήσης ώστε να στέλνει στον mqtt broker
 cmdInit(115200); //Η παράμετρος δεν λαμβάνεται υπόψη γιατί έχει οριστεί στην αρχή
 Switch1_status = Switch2_status = Switch1_status_pre = Switch2_status_pre = "IsOff";
 strcpy(Pressure, "950");
 //Serial.println("rst"); //Κάνε reset το Arduino Nano
}

void loop() 
{
 if (InternAvail == "true")
     timeClient.update(); //Όταν φτάσει η στιγμή ανανέωσε την ώρα από τον NTP Server
 blink_led(BUILTIN_LED);
 cmdPoll();
 //===================== Κάθε 1 sec επανάλαβε =====================================
 if ((millis() - interval) >= 1000)
    {
     interval = millis();
     tim += 1; //Ενημέρωσε το epoch time κατά 1 sec αν δεν λειτουργεί το NTP
     uptime += 1; //Ενημέρωσε το uptime κατά 1 sec
     //Serial.printf("Time: %02d:%02d:%02d\n", hour(tim)+2, minute(tim), second(tim)); //Debug Εμφάνισε ώρα από epoch local
     //Αν πέρασαν 5 δευτερόλεπτα μέτρησε την ένταση του σήματος
     if (five_secs < 1)
        {
         five_secs = 5; //Φόρτωσε πάλι την τιμή για τον επόμενο κύκλο
         if (WiFi.status() == WL_CONNECTED)
            {
             wifi_strength = WiFi.RSSI();
             S_Strength = String(WiFi.RSSI()) + "dBm";
            }
         else
            {
             wifi_strength = -100;
             S_Strength = "";
            }
        }
     else
         five_secs--;
    }
 //===================================================================================================
   
 //Αναζήτηση δικτύων wifi ασύγχρονο για την list_wifi_web()
 if (scan_state == 1)
    {
     if (millis() - lastScanMillis > 10000)
        {
         WiFi.scanNetworks(true, true); //Async = ναι, Δείξε τα κρυφά
         //Serial.print("\nScan start ... ");
         lastScanMillis = millis();
        }
     scan_state = 2;
    }
   
 //Αν υπάρχει σύνδεση στο διαδίκτυο τότε
 if (InternAvail == "true")
    {
     if (!client.connected()) //Αν δεν έχει συνδεθεί στον mqtt broker
         reconnect();         //Προσπάθησε να κάνεις σύνδεση
     if (client.connected())  //Αν υπάρχει σύνδεση στον broker
         client.loop();       //Έλεγξε για μηνύματα
    }
}
